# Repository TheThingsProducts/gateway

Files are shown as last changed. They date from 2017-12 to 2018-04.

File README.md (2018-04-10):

# The Things Gateway

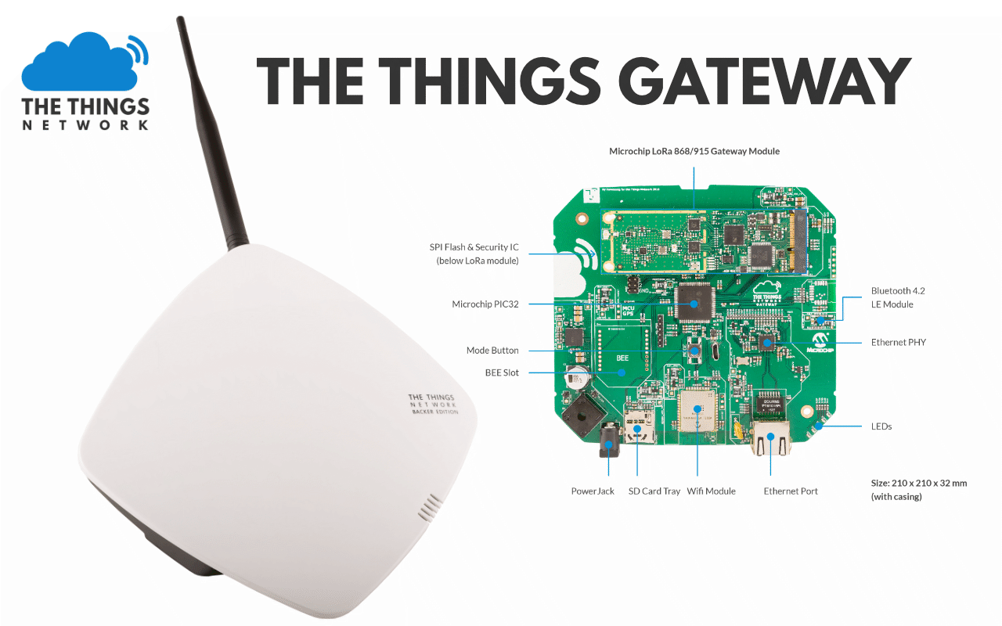
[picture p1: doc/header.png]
The Things Gateway


## Where to buy

A list of resellers can be found [here](https://www.thethingsnetwork.org/the-things-products).

## Enclosure

Designs of the enclosure can be found in the [enclosure](./enclosure) directory. These designs are licensed under a [Creative Commons Attribution-ShareAlike 4.0 International License](http://creativecommons.org/licenses/by-sa/4.0/).

## Hardware

Designs of the hardware can be found in the [hardware](./hardware) directory. These designs are licensed under a [Creative Commons Attribution-ShareAlike 4.0 International License](http://creativecommons.org/licenses/by-sa/4.0/).

## Firmware

Firmware source code is located in the [firmware](./firmware) directory. Firmware source code is released under a [MIT License](https://opensource.org/licenses/MIT).

## Feature Requests, Bug Reports and Support

- For feature requests and bug reports, create an [issue on Github](https://github.com/TheThingsProducts/gateway/issues)
- Community support on our [forum](https://www.thethingsnetwork.org/forum/c/gateways/the-things-gateway)
- Commercial support by [e-mail](mailto:support@thethingsproducts.com)

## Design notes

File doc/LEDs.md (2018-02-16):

# Gateway LEDs

| **LED 1** | **LED 2**  | **LED 3**  | **LED 4**  | **Status** |
| --- | --- | --- | --- | --- |
| On | Slow blink | | | Connecting to the internet |
| On | Fast blink | | | Could not connect to the internet |
| On | On | Slow blink | | Activating |
| On | On | Fast blink | | Could not activate (restart activation from step 1) |
| On | On | On | | Activated |
| On | On | On | On | Connected to the server |

## Details

| **LED** | **State** | **Reason** | **Cause** | **User Action** |
| --- | --- | --- | --- | --- |
| **1 - Power** | Off | No software is running | No power | Make sure the device is powered |
| | | | Incorrect firmware loaded | Make sure the correct firmware is loaded |
| | Slow | Software update in progress | | Wait |
| | On | Software is loaded and running |
| **2 - Internet** | Slow | Checking for internet |
| | Fast | No Ethernet or WiFi connection | No Ethernet link and WiFi connection failed; only possible way to connect is via the gateway’s WiFi access point (AP) | Connect to gateway's AP |
| | On | Has internet |
| **3 - Configuration** | Slow | Activating |
| | Fast | Bad configuration | No ID |Need to configure a gateway ID on the device |
| | | | Already activated | Need to configure valid key on the device |
| | | | Invalid key | Need to configure valid key on the device |
| | | | No router | Need to configure router in the TTN console |
| | | | Invalid URL | Correct URL in the TTN console |
| | On  | Activation successful |
| **4 - Connection** | Slow | Connecting MQTT |
| | On | Connected MQTT |
| **5 - Activity** | Single | Uplink/Downlink |

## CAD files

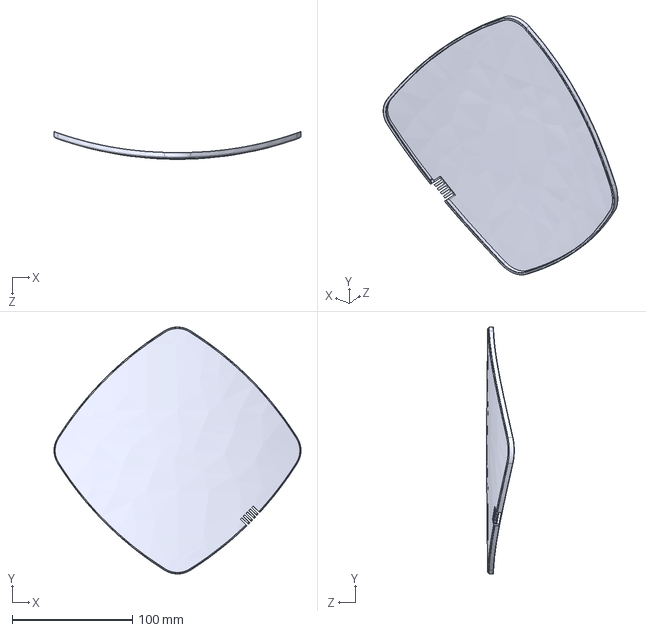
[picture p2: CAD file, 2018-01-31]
enclosure/TheThingsGateway-top.STEP
205.1 x 205.1 x 23.0 mm

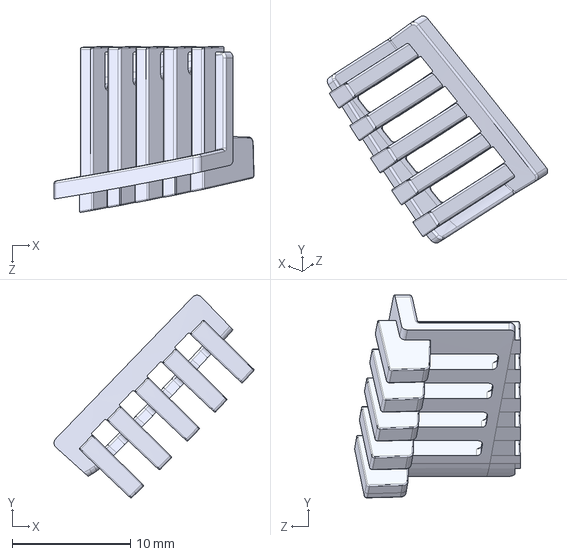
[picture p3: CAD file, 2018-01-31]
enclosure/TheThingsGateway-lightguide.STEP
16.9 x 17.1 x 14.0 mm

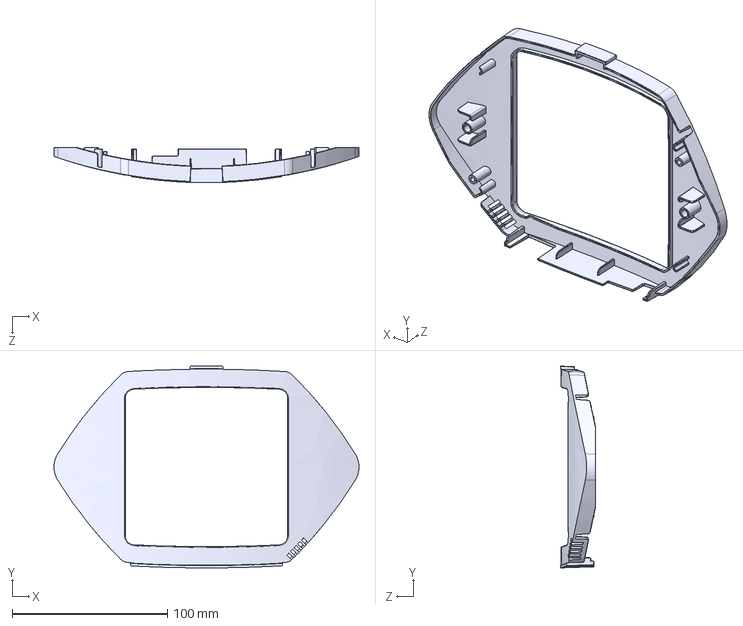
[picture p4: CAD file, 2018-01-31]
enclosure/TheThingsGateway-middle.STEP
196.4 x 130.0 x 22.9 mm

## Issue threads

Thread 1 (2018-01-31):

Reboot Loop - Reboot reason: 0x10 or 0x13

htdvisser, 2018-01-31:
From what I can see in the source code, that's a `RESET_REASON_WDT_TIMEOUT` (`0x10`).

Based on what I see on the [forum](https://www.thethingsnetwork.org/forum/t/ttn-gateway-central/10976) this happens **a lot**.

mbarnig, 2018-02-06:
In the TTN Gateway Central forum there are at least 57 identified users with a looping Gateway.

https://www.thethingsnetwork.org/forum/t/ttn-gateway-central/10976/408?u=mbarnig

johanstokking, 2018-02-06:
Please provide details here, not on the forum. From here we can link to the source files, pull requests and people can watch this issue getting closed.

Pinkfoxi, 2018-02-06:
The same as all other with troubles...
________________________________
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

frbayart, 2018-02-06:
The question is, which kind of details can help ?

grahamehorner, 2018-02-06:
here’s my little video looks almost identical with LEDS and quick flash on module that a reboot loop 🤪 https://twitter.com/grahamehorner/status/957325865892958208

johanstokking, 2018-02-06:
@frbayart @Pinkfoxi @grahamehorner

What could be of help for the maintainers is:

- How often does this occur
- Do you have logs from the gateway, and if so, can you provide them
- Can you tell more about the context, i.e. which model (915, 868), ethernet or wifi connected, etc

frbayart, 2018-02-06:
- this occur since I have connected my gateway there are 3 days
- I have tested on WiFi and ethernet ; I have also tested on a second internet connection
- model TTN Gateway Backer Edition 868

At this time I have no logs from the gateway , I guess I need to connect a serial on it to get logs right ?

grahamehorner, 2018-02-06:
- reboot interval approx. 30 seconds
- both WiFi and Ethernet inside/outside of firewall and different business ISPs
- TTN Gateway Backer Edititon - European 868

OK, looks like my gateway is officially STUFFED!!! NOW!! after a few days powered off, I power on today and only the first (Power) LED is solid with the second LED flashing rapidly, and its been like this for hours!?

robdobsn, 2018-02-06:
```
LORA: version: 01
LORA: Configuration failed, retry
LORA: Starting reconfiguration
LORA: version: 01
LORA: Configuration failed, retry
LORA: RESET MODULE
LORA: ChaSNTP: State change from 0 to 0
SNTP: State change from 0 to 0

**************************
*   The Things Network   *
*      G A T E W A Y     *
**************************
Firmware name: AmazingAckermann, type: 0, version: 1.0.0, commit: 917719b9, timestamp: 1498499973
Bootloader revision: 1, commit: 7167873a, timestamp: 1496411298
Build time: Jun 26 2017 19:59:53
Reboot reason: 0x13
BOOT: (persisted info) 6F 72 72 65 01 03 0A 3F 15 84 13 0F B1 25 98 B0

WIFI: Entering state 0
WIFI: Entering SCAN state 0

MAIN: Initialisation complete
LORA: Changing state from 0 to 0

MAIN: Leaving state 0
MAIN: Entering state 1
FLASH: Magic bytes found: wifi config present
FLASH: Magic bytes found: activation data present
FLASH: Magic bytes not found: no stored FOTA data present
FLASH: Loading Firmware Data
CNFG: (Firmware HASH (sha256)) FF FF FF FF FF FF FF FF FF FF FF FF FF FF FF FF FF FF FF FF FF FF FF FF FF FF FF FF FF FF FF FF
FLASH: Loading WiFi Data
CNFG: WiFi SSID:      rdint01
CNFG: WiFi key:       golgofrinsham
CNFG: WiFi conn_type: 1
CNFG: WiFi sec_type:  4
FLASH: Loading Activation Data
CNFG: Gateway ID:         atomic14-1
CNFG: Gateway Key:        ttn-account-v2.B8leUhot-xnHx1Vbrc8s1ZNcBzYuABED6BB71BXcv7hbDV2HxTGOh19yGIOwpdxLZrw70irKTZ4T5TcvH9BjIQ
CNFG: Account Server URL: https://account.thethingsnetwork.org
CNFG: Locked:             true
CNFG: Locked first time:  false

MAIN: Leaving state 1
MAIN: Entering state 2
INET: State change to 0
LORA: Initialisation complete
LORA: Changing state from 0 to 1
WIFI: Entering state 1
ETH: IP Address: 0.0.0.0
WIFI: Entering state 4
WIFI: Entering SCAN state 1
Scan is completed successfully
WIFI: Entering SCAN state 2
WIFI: Entering SCAN state 5
WIFI: Entering SCAN state 0
WIFI: Entering state 2
WIFI: Disabling modules
Head magic match void: trying to free an already freed block, ignore
WIFI: Entering state 3
SNTP: State change from 0 to 1
WIFI: Enabling modules for client
WIFI: Entering state 6

>WIFI: IP Address: 0.0.0.0
CB: INET: Gateway has WiFi
INET: State change to 2
INET: Connected to a network, waiting for DHCP lease, checking validity with ping
SNTP: State change from 1 to 2
LORA: Wait init complete, waiting for application.
LORA: Changing state from 1 to 2
WIFI: IP Address: 192.168.86.68
INET: State change to 3
INET: Ping probe
INET: Error sending probe on Eth
INET: Ping response from MRF24WN, set as default
INET: State change to 4
SNTP: State change from 2 to 3
MON: SYS Stack size: 3967
MON: heap usage: 147KB (156KB), free: 192KB
SNTP: State change from 3 to 4
SNTP: State change from 4 to 5
SNTP: State change from 5 to 6
SNTP: State change from 6 to 7
INET: State change to 5

MAIN: Leaving state 2
MAIN: Entering state 3

CNFG: Load online user config state change to 4
HTTP: Close active socket 0
CONF: ERROR REQUEST

CNFG: Downloading gateway configuration failed

CNFG: Load online user config state change to 8

CNFG: Communication ERROR

MAIN: Leaving state 3
MAIN: Entering state 2
INET: State change to 0
WIFI: Disabling modules
SNTP: State change from 7 to 8
CB: Disconnect
Head magic match void: trying to free an already freed block, ignore
SNTP: State change from 8 to 1
WIFI: Entering state 3
WIFI: Enabling modules for client
WIFI: Entering state 6
WIFI: IP Address: 0.0.0.0
CB: INET: Gateway has WiFi
INET: State change to 2
INET: Connected to a network, waiting for DHCP lease, checking validity with ping
SNTP: State change from 1 to 2
SNTP: State change from 2 to 3
SNTP: State change from 3 to 4
SNTP: State change from 4 to 5
MON: SYS Stack size: 3961
MON: heap usage: 147KB (157KB), free: 192KB
INET: State change to 3
INET: Ping probe
INET: Error sending probe on Eth
CB: INET: Ping Timeout
INET: Ping probe
INET: Error sending probe on Eth
SNTP: State change from 5 to 6
INET: Ping Timeout
INET: Ping probe
INET: Error sending probe on Eth
MON: SYS Stack size: 3961
MON: heap usage: 148KB (157KB), free: 191KB
INET: Ping Timeout
INET: State change to 1
WIFI: Disabling modules
SNTP: State change from 6 to 8
CB: Disconnect
Head magic match void: trying to free an already freed block, ignore
SNTP: State change from 8 to 1
WIFI: Entering state 3
WIFI: Entering state 4
WIFI: Entering SCAN state 1
Scan is completed successfully
WIFI: Entering SCAN state 2
WIFI: Entering SCAN state 3
Head magic match void: trying to free an already freed block, ignore
SNTP: State change from 1 to 1
WIFI: Entering SCAN state 4
WIFI: Entering SCAN state 5
WIFI: Entering SCAN state 0
WIFI: Entering state 5
WIFI: Enabling modules for server
WIFI: Entering state 6
WIFI: IP Address: 192.168.84.1
CB: MON: SYS Stack size: 3961
MON: heap usage: 147KB (157KB), free: 192KB
MON: SYS Stack size: 3961
MON: heap usage: 147KB (157KB), free: 192KB
MON: SYS Stack size: 3961
MON: heap usage: 147KB (157KB), free: 192KB
MON: SYS Stack size: 3961
MON: heap usage: 147KB (157KB), free: 192KB
MON: SYS Stack size: 3961
MON: heap usage: 147KB (157KB), free: 192KB
MON: SYS Stack size: 3961
MON: heap usage: 147KB (157KB), free: 192KB
MON: SYS Stack size: 3961
MON: heap usage: 147KB (157KB), free: 192KB
MON: SYS Stack size: 3961
MON: heap usage: 147KB (157KB), free: 192KB
MON: SYS Stack size: 3961
MON: heap usage: 147KB (157KB), free: 192KB
MON: SYS Stack size: 3961
MON: heap usage: 147KB (157KB), free: 192KB
MON: SYS Stack size: 3961
MON: heap usage: 147KB (157KB), free: 192KB
MON: SYS Stack size: 3961
MON: heap usage: 147KB (157KB), free: 192KB
INET: Trying to connect to WiFi router again (after 120 seconds)
INET: State change to 0
WIFI: Disabling modules
CB: Disconnect
Head magic match void: trying to free an already freed block, ignore
SNTP: State change from 1 to 1
WIFI: Entering state 3
WIFI: Enabling modules for client
WIFI: Entering state 6
WIFI: IP Address: 0.0.0.0
CB: INET: Gateway has WiFi
INET: State change to 2
INET: Connected to a network, waiting for DHCP lease, checking validity with ping
SNTP: State change from 1 to 2
MON: SYS Stack size: 3961
MON: heap usage: 147KB (157KB), free: 192KB
INET: State change to 3
INET: Ping probe
INET: Error sending probe on Eth
SNTP: State change from 2 to 6
INET: Ping Timeout
INET: Ping probe
INET: Error sending probe on Eth
WIFI: IP Address: 192.168.86.68
INET: Ping Timeout
INET: Ping probe
INET: Error sending probe on Eth
INET: Ping response from MRF24WN, set as default
INET: State change to 5

MAIN: Leaving state 2
MAIN: Entering state 3

CNFG: Load online user config state change to 4
HTTP: Starting connection
HTTPS: Connection Opened: Starting TLS Negotiation
HTTP: Wait for TLS Connect
HTTP: TLS Connection Opened: Starting Clear Text Communication
HTTP: Got 1289 bytes
MON: SYS Stack size: 2837
MON: heap usage: 228KB (233KB), free: 111KB
HTTP: Connection Closed
HTTP: Close active socket 1
CONF: Parsing response token: HTTP/1.1 200 OK
CONF: ROUTER URL: mqtts://bridge.eu.thethings.network:8883
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
grahamehorner, 2018-02-06:
interesting note in code

```
static void restart_lora_configuration(void)
{
    SYS_DEBUG(SYS_ERROR_FATAL, "LORA: RESET MODULE\r\n");
    DRV_USART_Close(appData.USARTHandle);
    **// TODO Verify untested fix. Here we power cycle the module as resetting (done in loraInit) the module was not
    // enough.**
    loraSet(false);
    vTaskDelay(100 / portTICK_PERIOD_MS);
    loraSet(true);
    _setState(APP_LORA_INIT);
}
```

grahamehorner, 2018-02-06:
BOOT: (persisted info)
[6F 72 72 65]  = magic -  errA ? should be erro according to code ?
[01]                 = type   -   ERROR_MESSAGES_TYPE_POWER_CYCLE

and based on the information at hand given the magic number is incorrect according to the code I've seen; this would suggest a memory pointer issue that is corrupting something ?

cyberjunky, 2018-02-07:
@johanstokking

**Here my complete logs with extra debugging enabled (own compiled fw)**

I compile my own fw from this github repo, I enabled extra debugging (although it's just some lora and flash debugging)

By doing this:
`vi src/system_config/TTN_Gateway_v1/system_init.c

SYS_DEBUG_INIT debugInit =
{
    .moduleInit = {0},
    .errorLevel = SYS_ERROR_DEBUG
};
`
I first deleted activation from gw, and flashed fw via sd card, I then started activation page, and created new gateway. Connected laptop via wifi and choose Ethernet as network, then gw restarted and I lost internet connection on my laptop, see it get activated and connected in ttn console, it send some packets and stayed running for 223 second, then it rebooted all of a sudden, and started again, but seems to fail te get response from NTP servers, it tries for a while and seem to get internet connection again, when it gets TLS traffic, shortly after that you see this in the log:

> MON: heap usage: 263KB (269KB), free: 76KB
   SNTP: State change from 0 to 0
   SNTP: State change from 0 to 0

Then it reboots with all 5 leds on, off, on, off on, etc etc... No logging in console. The gw doesn't get out of this loop. I can reproduce this many times since I got the gateway.

As you can see I don't have the LORA RESET messages like others have in the logs.

See info screen shots and logs attached, fresh activation....txt and 1.png are before sudden reboot, it continues in sudden reboot....txt and 2.png but at that end it starts boot looping.

Also see the last line in sudden reboot...txt, I see this every time when a reboot loop starts:

> HTTP: Close active socket 1300,"radio":1,"bandw

So right after closing the TLS connection, some output of LORA module garbled:

>
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

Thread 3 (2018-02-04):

Is it on purpose LoRa_Tx = LoRa_Rx on gateway/hardware/TTN_Gateway_V2.3.1.pdf

mchevroulet, 2018-02-04:
Is it on purpose that LoRa_TX is shorted with LoRa_Rx on schematics lora.SchDoc in gateway/hardware/TTN_Gateway_V2.3.1.pdf ? Or is it just a print artefact ?

This is page 8/9, revision 1.0 of document dated 2018-1-31.

Closed 2018-03-15.

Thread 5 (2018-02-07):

Gateway Boot Issues

grahamehorner, 2018-02-07:
My gateway was effected by the reboot issue; now the gateway fails to boot, the power LED is solid; while the second LED is flashing rapidly ?

grahamehorner, 2018-02-07:
I have attempt to update via SD card without success, there is no output via serial port logs

johanstokking, 2018-02-07:
Duplicate of #1

grahamehorner, 2018-02-07:
This is not a duplicate of #1 as I cant connect to the gateway at all the AP is not visible and the gateway is not rebooting but is stuck with regards the boot sequence with power LED solid and 2nd LED flashing rapidly; which is quite a different set of issues to the Reboot Loop

grahamehorner, 2018-02-07:
Please reopen

grahamehorner, 2018-02-07:
I'm unsure this is a soft/firmware issue, as after many attempts and reboots the gateway is now showing up as an AP and I'm able to connect; and the gateway now looks to have successfully updated it's firmware

Version Info |  -- | -- Hardware: | v1
Bootloader: | r1-7167873a (2017-06-02T13:48:18Z)
Firmware: | v1.0.1-0407f7eb (2018-02-06T10:58:41Z)

however the #1 is still present; If hardware issues are still to be logged; this IMHO is definitely an odd one? may be a dry joint or something? physical with the gateway

grahamehorner, 2018-02-16:
The gateway is now back to not showing up as an AP or updating, this time  tried 14 reboots, nothing still not seeing the gateway as an AP so can’t verify if the status?  LEDs are same as above

grahamehorner, 2018-02-20:
After leaving the gateway off for approx. 3days my gateways is still in an unstable state where I'm unable to see the gateways as an access point or update the firmware via the SD card after a full reset ?

grahamehorner, 2018-02-24:
other update booted the gateway this morning, and this time it shows up as an AP; will try and update firmware

grahamehorner, 2018-02-25:
Update seemed to work, then gateway was stuck in reboot loop 😭

grahamehorner, 2018-02-28:
my gateway is shown that the card is ND this never changes even after rebooting or full reset, when the gateway decides to start? Please can any one advise?!

KrishnaIyer, 2018-09-27:
@grahamehorner: Please let us know if you still face this issue after  upgrading to firmware `v1.0.5` or if we can close this.

grahamehorner, 2018-09-27:
@KrishnaIyer I'm unable to perform any update to the gateway as detailed in numerous posts on forums, the gateway is unresponsive to any attempt to update or connection via FDTI, its now an as much use as an expensive door stop or chocolate fireguard :'(  very very frustrating especially when it has been so long without a resolution or an offer of exchange/replacement unit

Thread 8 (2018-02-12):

Gateway loses network connection and needs power cycle to recover

avbentem, 2018-02-12:
My gateway lost its WiFi connection over an hour ago, and could not recover without cycling its power, like others have reported on the forum as well. Some observations:

## While failing to reconnect

- I think it had been running for about 20 hours. (Certainly not a full day; I took a picture at 9 PM last night, when it was not connected; at around 6 PM today it showed as "Last seen: 54 minutes ago".)

- It might have been in AP mode (LED 2 flashing slow and fast).

- Plugging in a debug cable restarted the gateway.

- The unexpected reset of the gateway did not resolve this.

- After the reset, it kept reporting things like:

    ```text
    INET: Trying to connect to WiFi router again (after 120 seconds)
    INET: State change to 0
    MON: SYS Stack size: 3959
    MON: heap usage: 148KB (148KB), free: 191KB
    INET: No Ethernet and WiFi link (after 10 seconds)
    INET: State change to 1
    ```

- The FRITZ!Box 7360 WiFi AP did not log any connection attempts.

- Restarting the WiFi AP did not resolve this. All other devices (Sonos, Apple TV, Chromecast, laptop, tablet, telephone) reconnected just fine.

- Attaching an ethernet cable did not resolve this. The connector's LEDs were flashing, but I forgot to check if the router showed a connection.

- Finally cycling power resolved it.

## During normal operation

- When connected to ethernet and unplugging the cable, it nicely recovers by connecting to WiFi. (LED 2 flashing for some time, while LED 1 and 3 are solid.)

- Restarting the AP when the gateway is connected to its WiFi, makes the gateway reboot:

    ```text
    LORA: Accepted packet
    MQTT: Sending UPLINK failed: -1

    MAIN: MQTT error

    MAIN: Leaving state 5
    SNTP: State change from 0 to 0
    SNTP: State change from 0 to 0
    ```

    Next, when it cannot connect to WiFi after restarting, it starts in AP mode (LED 2 flashing) but eventually connects to WiFi again, and all is good.

avbentem, 2018-02-14:
It kept running for 36 hours, but eventually got into a non-recoverable network problem again. The new logs shows:

- It _can_ recover from some MQTT problems (10:07 this morning, Amsterdam time).

- Sometimes it cannot recover from MQTT problems, even though it has an internet connection and can nicely fetch its configuration from the internet.

So I wonder:

- Could the non-recoverable problem have started by MQTT problems on the server, around 2018-02-14 17:05:15 (Amsterdam time), and be different MQTT problems than the one it could recover from?

## Nicely recovering from `MQTT: Sending status failed` (after running for 36 hours)

- Running my own firmware, with debug logging enabled. (See PR #7.)

- Logging started 2018-02-12 22:42:10. I'm not sure how long the gateway was running then, but not for very long.

- It failed about 36 hours later, `MQTT: Sending status failed`, but recovered. All logs here have `MON:`-lines removed for brevity:

	```text
	[2018-02-14 10:06:11] MQTT: Sending UPLINK OK
	[2018-02-14 10:06:22] MQTT: Sending status packet
	[2018-02-14 10:06:22] MQTT: Sending status succeeded: 1351
	[2018-02-14 10:06:47] LORA: Packet dropped! Bad CRC
	[2018-02-14 10:06:52] MQTT: Sending status packet
	[2018-02-14 10:06:52] MQTT: Sending status succeeded: 1352
	[2018-02-14 10:07:07] LORA: Packet dropped! Bad CRC
	[2018-02-14 10:07:22] MQTT: Sending status packet
	[2018-02-14 10:07:22] MQTT: Sending status succeeded: 1353
	[2018-02-14 10:07:52] CB: MQTT: Sending status packet
	[2018-02-14 10:07:54] MQTT: Sending status failed
	[2018-02-14 10:07:54]
	[2018-02-14 10:07:54] MAIN: MQTT error
	[2018-02-14 10:07:55]
	[2018-02-14 10:07:55] MAIN: Leaving state 5
	[2018-02-14 10:07:57] MAIN: Entering state 6
	[2018-02-14 10:07:57] INET: State change to 0
	[2018-02-14 10:07:57] WIFI: Disabling modules
	[2018-02-14 10:07:57] SNTP: State change from 7 to 8
	[2018-02-14 10:07:57] CB: Disconnect
	[2018-02-14 10:07:57] Head magic match void: trying to free an already freed block, ignore
	[2018-02-14 10:07:57] SNTP: State change from 8 to 1
	[2018-02-14 10:07:57] WIFI: Entering state 3
	[2018-02-14 10:07:58] WIFI: Enabling modules for client
	[2018-02-14 10:07:58] WIFI: Entering state 6
	[2018-02-14 10:07:58] WIFI: IP Address: 0.0.0.0
	[2018-02-14 10:08:00] CB: INET: Gateway has WiFi
	[2018-02-14 10:08:00] INET: State change to 2
	[2018-02-14 10:08:00] INET: Connected to a network, waiting for DHCP lease, checking validity with ping
	[2018-02-14 10:08:01] SNTP: State change from 1 to 2
	[2018-02-14 10:08:04] CB: MON: SYS Stack size: 2833
	[2018-02-14 10:08:05] INET: State change to 3
	[2018-02-14 10:08:05] INET: Ping probe
	[2018-02-14 10:08:05] INET: Error sending probe on Eth
	[2018-02-14 10:08:05] LORA: Accepted packet
	[2018-02-14 10:08:06] SNTP: State change from 2 to 6
	[2018-02-14 10:08:09] INET: Ping Timeout
	[2018-02-14 10:08:09] INET: Ping probe
	[2018-02-14 10:08:09] INET: Error sending probe on Eth
	[2018-02-14 10:08:11] LORA: Accepted packet
	[2018-02-14 10:08:13] INET: Ping Timeout
	[2018-02-14 10:08:13] INET: Ping probe
	[2018-02-14 10:08:13] INET: Error sending probe on Eth
	[2018-02-14 10:08:16] CB: Disconnect
	[2018-02-14 10:08:17] INET: Ping Timeout
	[2018-02-14 10:08:17] INET: State change to 1
	[2018-02-14 10:08:17] WIFI: Disabling modules
	[2018-02-14 10:08:17] Head magic match void: trying to free an already freed block, ignore
	[2018-02-14 10:08:17] SNTP: State change from 6 to 1
	[2018-02-14 10:08:17] WIFI: Entering state 3
	[2018-02-14 10:08:18] WIFI: Entering state 4
	[2018-02-14 10:08:18] WIFI: Entering SCAN state 1
	[2018-02-14 10:08:18] Scan is completed successfully
	[2018-02-14 10:08:18] WIFI: Entering SCAN state 2
	[2018-02-14 10:08:18] WIFI: Entering SCAN state 3
	[2018-02-14 10:08:18] Head magic match void: trying to free an already freed block, ignore
	[2018-02-14 10:08:18] SNTP: State change from 1 to 1
	[2018-02-14 10:08:18] WIFI: Entering SCAN state 4
	[2018-02-14 10:08:19] WIFI: Entering SCAN state 5
	[2018-02-14 10:08:19] WIFI: Entering SCAN state 0
	[2018-02-14 10:08:19] WIFI: Entering state 5
	[2018-02-14 10:08:19] WIFI: Enabling modules for server
	[2018-02-14 10:08:19] WIFI: Entering state 6
	[2018-02-14 10:08:19] WIFI: IP Address: 192.168.84.1
	[2018-02-14 10:08:20] LORA: Accepted packet
	[2018-02-14 10:08:24] CB: MON: SYS Stack size: 2833
	[2018-02-14 10:08:36] LORA: Accepted packet
	[2018-02-14 10:08:43] LORA: Accepted packet
	[2018-02-14 10:08:43] LORA: Packet dropped! Bad CRC
	[2018-02-14 10:09:12] LORA: Accepted packet
	[2018-02-14 10:09:17] LORA: Accepted packet
	[2018-02-14 10:09:23] LORA: Accepted packet
	[2018-02-14 10:09:23] LORA: Packet dropped! Bad CRC
	[2018-02-14 10:10:17] INET: Trying to connect to WiFi router again (after 120 seconds)
	[2018-02-14 10:10:17] INET: State change to 0
	[2018-02-14 10:10:17] WIFI: Disabling modules
	[2018-02-14 10:10:17] CB: Disconnect
	[2018-02-14 10:10:17] Head magic match void: trying to free an already freed block, ignore
	[2018-02-14 10:10:17] SNTP: State change from 1 to 1
	[2018-02-14 10:10:17] WIFI: Entering state 3
	[2018-02-14 10:10:18] WIFI: Enabling modules for client
	[2018-02-14 10:10:18] WIFI: Entering state 6
	[2018-02-14 10:10:18] WIFI: IP Address: 0.0.0.0
	[2018-02-14 10:10:19] CB: INET: Gateway has WiFi
	[2018-02-14 10:10:19] INET: State change to 2
	[2018-02-14 10:10:19] INET: Connected to a network, waiting for DHCP lease, checking validity with ping
	[2018-02-14 10:10:20] SNTP: State change from 1 to 2
	[2018-02-14 10:10:21] WIFI: IP Address: 192.168.178.53
	[2018-02-14 10:10:23] LORA: Kick LoRa module with ACK after not acked it for 60s
	[2018-02-14 10:10:24] INET: State change to 3
	[2018-02-14 10:10:24] INET: Ping probe
	[2018-02-14 10:10:24] INET: Error sending probe on Eth
	[2018-02-14 10:10:24] INET: Ping response from MRF24WN, set as default
	[2018-02-14 10:10:24] INET: State change to 5
	[2018-02-14 10:10:24]
	[2018-02-14 10:10:24] MAIN: Leaving state 6
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
avbentem, 2018-02-18:
Update: it has been running for over 3 days (since 2018-02-14 23:18) now. It has seen a bunch of `MQTT: Sending UPLINK failed` and `MQTT: Sending status failed`, has rebooted 8 times (3 of which for `MAIN: Rebooting gateway for firmware update check`), but has always recovered during the last 3 days.

(Still running my own patched firmware, [being `develop` from February 14th with debug logging enabled](https://github.com/TheThingsProducts/gateway/issues/1#issuecomment-365746884).)

grahamehorner, 2018-02-18:
@avbentem that’s great news, so given the gateway reboots every 24hrs in the code, you’ve got 5 unattend reboots which is a MASSIVE improvement by far, great work

avbentem, 2018-02-18:
To clarify, @grahamehorner, the 5 unwanted reboots occurred after running into a `MAIN: MQTT error` (which, however, does not _always_ imply a reboot; often it just recovers without such reboot and I've not yet discovered in which cases it deems a reboot required), and seem unrelated to reboot issues during activation, like those reported in #1.

I'm eager to test what happens when I make my router disconnect the WiFi, or shutdown the router altogether. But I don't want to interfere with the current test which meanwhile has given me a log file of almost 4 days now, and which may be useful to compare to server side logs, to find the cause of MQTT issues.

grahamehorner, 2018-02-18:
@avbentem that sound like a great plan, wondering if the gateway should have some SNMP added late to allow remote diagnostics and or management;  but it great to hear that progress is begin made

johanstokking, 2018-02-20:
@avbentem do you have the dates and times of this disconnect? We have had some issues with EU endpoints, including MQTT, very recently. This may be server initiated disconnects which the gateway recovered from naturally.

cc @htdvisser

avbentem, 2018-02-20:
Still running, almost 6 days now. And it nicely recovered at about 17:40 GMT+1, without me interfering, from the major EU region problems that [were happening today](https://www.thethingsnetwork.org/forum/t/eu-region-routing-services-major-outage/12768).

During the problems I got into regular reboots with `RQMQTT: Connection failed` followed by `MAIN: MQTT error` and `Reboot reason: 0x10`.

At other times in the recent logs I see `MQTT: Connection lost` (rather than `failed`) like the following:

```text
LORA: Accepted packet
MQTT: Sending UPLINK OK
LORA: Accepted packet
MQTT: Sending UPLINK OK
MQTT: Sending status packet
MQTT: Sending status succeeded: 1
MQTT: Connection lost

MAIN: MQTT error
```

...followed by many:

```text
MQTT: GOT IP: 52.169.76.203
Connecting to: 52.169.76.203
MQTT: Opening socket timed out, restarting
MQTT: GOT IP: 52.169.76.203
Connecting to: 52.169.76.203
MQTT: Opening socket timed out, restarting
MQTT: GOT IP: 52.169.76.203
Connecting to: 52.169.76.203
MQTT: Opening socket timed out, restarting
```

So, it seems `Connection failed` (often) yields a reboot, but `Connection lost` makes the firmware try forever.

avbentem, 2018-02-20:
@johanstokking, here's a full log since February 14th:

[arjan-gateway-20180220.log.zip](https://github.com/TheThingsProducts/gateway/files/1741101/arjan-gateway-20180220.log.zip)

Like earlier, this is using my own firmware, based on the February 14th `develop` branch, only changed to enable debug logging and the debug cable's baud rate. It's been compiled with a free version (or a trial?) of the Microchip XC32 v1.42 compiler.

avbentem, 2018-02-20:
@johanstokking and @htdvisser I've edited my comment above a few times.

avbentem, 2018-03-02:
Quick update: my gateway nicely recovered from today's https://status.thethings.network/incident/45 So, it has not needed any reboot since February 14th.

```text
[2018-03-02 10:28:05] MQTT: Sending UPLINK OK
```

However, half an hour later, it ran into:

```text
[2018-03-02 11:02:43] MQTT: Sending UPLINK OK
[2018-03-02 11:02:45]
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

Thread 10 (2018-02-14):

Unable to turn off wifi AP mode on the gateway

sourceperl, 2018-02-14:
Hi,

I use the ethernet link to connect the gateway to the internet.

After activation the wifi AP mode is not turn off and my gateway always broadcast the SSID ""Things-Gateway-0001ECxxxxxx". The default password "thethings" also remain active... It's really not secure.

I'm unable to fix  this. I try the embedded web manager, the serial debug (the wifi cmd seem not work) and https://console.thethingsnetwork.org/gateways.

My firmware is :
(Firmware HASH (sha256)) 69 AE B7 78 1F 49 4E 7F BC B6 C7 CD 9C 59 4F 5D FA AA 3D 81 D4 9C 56 90 A6 83 81 98 FF 18 88 6A

Bootloader is:
Firmware name: AmazingAckermann, type: 0, version: 1.0.0, commit: 917719b9, timestamp: 1498499973
Bootloader revision: 1, commit: 7167873a, timestamp: 1496411298
Build time: Jun 26 2017 19:59:53

sourceperl, 2018-02-15:
after some test, i find the command "if wlan0 down" this turn off wifi access point but it's not persistent after reboot.

IJeffray, 2018-02-20:
I would very much like to run with Ethernet only and the WLAN module completely disabled.  For security, and for keeping the air clear.   I'm very surprised this isn't an option already as it would surely be simple to implement.   It could even be 'automatic' - if Ethernet is present at bootup, disable the Wifi -- no need for any user interface.

cyberjunky, 2018-02-24:
Sometimes you might need the wifi to be able to reconfigure/activate it, maybe it's an idea to toggle wifi on off by using a file flag on the sd card, so when a user creates a file on the sd card named `'nowifi' `disable it.

wintermi, 2018-03-15:
Just got my TTN Gateway and have the same issue.  I only want to use the Ethernet connection and the only way I have found at the moment to remove the Wifi AP is to actually connect the Wifi.  Not a good solution as now both Wifi & Ethernet is configured.

lanmarc77, 2019-02-18:
I am not sure if I understood this thread. But I still see the SSID being broadcasted in the current firmware even though I have working ethernet connection and /info also only displays Ethernet as connection type.
Inserting the following code in app_wifi.c at line 354 finally stops the broadcast and also saves 0.3W of power:

`_activeConfig = CNFG_NONE;`
`_event=EVENT_NONE;`
`return;`

Who also wants to disable the built in http server comments line 739 in system_config.h:

`//#define TCPIP_STACK_USE_HTTP_SERVER`

hagenbuch, 2019-02-28:
Does this mean I have to compile and install the complete firmware for the TTN gateway?

If yes, I'd rather wait until the first scandal shows up where some attacker exploited a company successfully and came in through their open Things Gateway AP /s

lanmarc77, 2019-02-28:
Yes it does mean compiling and installing the firmware yourself. If you do have the .hex file you only would need an SD card to actually update the gateway. Also compiling is not really more than installing the freely availble IDEs linked in the readme of this repository and cloning this repository. As I already did the detective work how to minimally change the code to achieve the given features this can be done in under an hour easily.
And also yes you are free to wait until something (might) happen but then I do not see how this helps in any way to add features WE want. I so value the possibility to have an open device, knowing I do not get an SLA but be able to do something with it myself.

KrishnaIyer, 2019-03-06:
@lanmarc77: what is the version of your firmware?

lanmarc77, 2019-03-06:
@KrishnaIyer The base of the mentioned modification was v1.0.5 which is the current version of the firmware since July 2018

MartinNPN, 2019-05-14:
@lanmarc77 thanks for the easy solution :)

devZer0, 2023-05-16:
this ticket is closed - but how can i disable wifi now ?

what do i need to do ?

Closed 2018-04-21.

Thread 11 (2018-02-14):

Bootloader code or image availability?

cyberjunky, 2018-02-14:
My gateway stopped working all together it seems, no lights lit up other than the power circuit ones (2) , no working firmware updates via SD card or responses on mode button presses can be seen.
Will the bootloader code and/or image (hex file) be made available? Either public in this repo or privately disclosed/shared so I can try to get it running again by re-flashing it via ISCP port using a debugger tool like PicKit3 or ICD3.

cyberjunky, 2018-02-20:
@rish-c Rich-c are you able to supply me the bootloader or memory hex to be flashed using a debugger tool so my gw boots again? Maybe even via PM.
This way I can perhaps get it up and running again and start helping to debug the timing issues together with @avbentem

cyberjunky, 2018-02-23:
Yes, I managed to unbrick my gateway (which was bricked due to my own fault) I flashed the bootloader.hex from the feature/merging_bootloader branch using my ICD3  and it came to life again with bootloader r2, it didn't reboot with reason 0x10 ever since!
I also flashed the firmware from the same branch and for the first time ever I got my devices to use the gateway, it has traffic! Some prove...
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

cyberjunky, 2018-02-24:
I forgot to ask; what is the use case of the firmware-with-bootloader.hex file? Flashing it using the ICD3 didn't result in a working gateway, only after I flashed the bootloader.hex it started to run. The next morning it still runs without a glitch, before this the longest run period was 3-4 minutes.

martinichka, 2018-02-24:
Hi Rob,

The firmware-with-bootloader.hex is a combination of the bootloader with
the latest application. Such a file is used during production, and should
only be programmed using an external programmer (so no via SD card).

So the fact that it did not work when you flashed the with-bootloader image
using ICD is blocking this PR.

We will look in to it.

The fact that it did reboot after since is due to the corrected clock
settings. For now only possible to change by an external programmer. As you
know we are working on a solution that does not require an external
programmer.

Marten

Op za 24 feb. 2018 08:27 schreef Ron Klinkien <notifications@github.com>:

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

cyberjunky, 2018-02-24:
Marten, I noticed the clock setting changes in the commit.
About the firmware-with-bootloader file I flashed it with the default settings like in the screenshot above. But I noticed with this file and with bootloader.hex that the programmer gave a warning about code that is located at addresses that do not exist when loading the hex, this seems bogus for at least one of them as flashing with bootloader.hex file succeeded anyway.
This the message I'm referring too:

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

If you want me to re-test something let me know.

martinichka, 2018-02-24:
If you could re-test with a full erase and flash the firmware-with-bootloader.hex, to see if that is running, that would be a great help. On the devices here it is working and it is the standard procedure at production. The `contains code that is located at addresses that do not exist on the PIC32MZ2048EFM144` we also noticed. It is not new, but I will look in to that.

cyberjunky, 2018-02-24:
What I did to brick it (if i remember correctly) is flashing the firmware.hex to the device using the ICD3, when all the lights went out and stayed out then I realized (a bit late) that the bootloader was missing in the file and gone from my gateway. I didn't test re-flashing after the bootloader.hex succeeded.
I fully erased and re-flashed with firmware-with-bootloader.hex just now 5 times in a row, and it worked flawlessly.
So you can unblock this PR, probably the wrong state without erase first was the cause.

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

martinichka, 2018-02-24:
That is great news. Thanks for retesting.

htdvisser, 2018-03-12:
We added the bootloader in PR #16; Links to hex files with firmware + bootloader are added to the [README in firmware dir](https://github.com/TheThingsProducts/gateway/tree/develop/firmware#firmware-with-bootloader) (currently only in `develop`, expected be merged to `master` soon)

Closed 2018-03-12.

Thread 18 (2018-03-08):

Not connecting to Network / Gateway Card not defined

samuel-puschacher, 2018-03-08:
Hello,
I can't get my Gateway connecting to TTN
I get stuck at Step 4.
When I open the Gateway Info Page I get the following:
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

When I refresh the Page, the LoRa Config is lost, the Concentrator not defined.
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

I tried WiFi & Ethernet in many Combinations and different Networks. Also reset the Gateway, by pressing the Button during Power up.

Edit: It seems to be in a Boot loop
```

**************************
*   The Things Network   *
*      G A T E W A Y     *
**************************
Firmware name: AmazingAckermann, type: 0, version: 1.0.0, commit: 917719b9, timestamp: 1498499973
Bootloader revision: 1, commit: 7167873a, timestamp: 1496411298
Build time: Jun 26 2017 19:59:53
Reboot reason: 0x43
BOOT: (persisted info) 6F 72 72 65 01 03 0E 9A 98 8A F2 4E 49 9A 09 B4

WIFI: Entering state 0
WIFI: Entering SCAN state 0

MAIN: Initialisation complete
LORA: Changing state from 0 to 0

MAIN: Leaving state 0
MAIN: Entering state 1
FLASH: Magic bytes found: wifi config present
FLASH: Magic bytes found: activation data present
FLASH: Magic bytes not found: no stored FOTA data present
FLASH: Loading Firmware Data
CNFG: (Firmware HASH (sha256)) FF FF FF FF FF FF FF FF FF FF FF FF FF FF FF FF FF FF FF FF FF FF FF FF FF FF FF FF FF FF FF FF
FLASH: Loading WiFi Data
CNFG: WiFi SSID:      RP.1.net
CNFG: WiFi key:       ********
CNFG: WiFi conn_type: 1
CNFG: WiFi sec_type:  4
FLASH: Loading Activation Data
CNFG: Gateway ID:         ttn-noe-001
CNFG: Gateway Key:        ttn-account-v2.******************************************************************
CNFG: Account Server URL: https://account.thethingsnetwork.org
CNFG: Locked:             true
CNFG: Locked first time:  false

MAIN: Leaving state 1
MAIN: Entering state 2
INET: State change to 0
LORA: Initialisation complete
LORA: Changing state from 0 to 1
WIFI: Entering state 1
ETH: IP Address: 0.0.0.0
WIFI: Entering state 4
WIFI: Entering SCAN state 1
Scan is completed successfully
WIFI: Entering SCAN state 2
WIFI: Entering SCAN state 5
WIFI: Entering SCAN state 0
WIFI: Entering state 2
WIFI: Disabling modules
Head magic match void: trying to free an already freed block, ignore
WIFI: Entering state 3
SNTP: State change from 0 to 1
WIFI: Enabling modules for client
WIFI: Entering state 6

>WIFI: IP Address: 0.0.0.0
CB: INET: Gateway has WiFi
INET: State change to 2
INET: Connected to a network, waiting for DHCP lease, checking validity with ping
SNTP: State change from 1 to 2
CB: LORA: Wait init complete, waiting for application.
LORA: Changing state from 1 to 2
WIFI: IP Address: *.*.*.96
INET: State change to 3
INET: Ping probe
INET: Error sending probe on Eth
INET: Ping response from MRF24WN, set as default
INET: State change to 4
SNTP: State change from 2 to 3
MON: SYS Stack size: 3967
MON: heap usage: 147KB (156KB), free: 192KB
SNTP: State change from 3 to 4
SNTP: State change from 4 to 5
SNTP: State change from 5 to 6
SNTP: State change from 6 to 7
INET: State change to 5

MAIN: Leaving state 2
MAIN: Entering state 3

CNFG: Load online user config state change to 4
HTTP: Close active socket 0
HTTP: Starting connection
HTTPS: Connection Opened: Starting TLS Negotiation
HTTP: Wait for TLS Connect
HTTP: TLS Connection Opened: Starting Clear Text Communication
HTTP: Got 1287 bytes
HTTP: Connection Closed
HTTP: Close active socket 1
CONF: Parsing response token: HTTP/1.1 200 OK
CONF: ROUTER URL: mqtts://bridge.eu.thethings.network:8883

CNFG: Load online user config state change to 6
FREQ: APP_URL_Buffer: https://account.thethingsnetwork.org/api/v2/frequency-plans/EU_863_870
HTTP: Starting connection
HTTPS: Connection Opened: Starting TLS Negotiation
HTTP: Wait for TLS Connect
HTTP: TLS Connection Opened: Starting Clear Text Communication
HTTP: Got 1232 bytes
MON: SYS Stack size: 2863
MON: heap usage: 227KB (233KB), free: 111KB
HTTP: Connection Closed
HTTP: Close active socket 1

CNFG: Load online user config state change to 7

CNFG: Configuring LoRa module
LORA: Changing state from 2 to 4
LORA: Starting reconfiguration
LORA: version: 01
LORA: Configuration failed, retry
LORA: Starting reconfiguration
LORA: version: 01
LORA: Configuration failed, retry
LORA: Starting reconfiguration
MON: SYS Stack size: 2863
MON: heap usage: 151KB (233KB), free: 188KB
LORA: version: 01
LORA: Configuration failed, retry
LORA: RESET MODULE
LORA: ChaSNTP: State change from 0 to 0
SNTP: State change from 0 to 0

**************************
*   The Things Network   *
*      G A T E W A Y     *
**************************
Firmware name: AmazingAckermann, type: 0, version: 1.0.0, commit: 917719b9, timestamp: 1498499973
Bootloader revision: 1, commit: 7167873a, timestamp: 1496411298
Build time: Jun 26 2017 19:59:53
Reboot reason: 0x53
BOOT: (persisted info) 6F 72 72 65 01 03 0E 9A 98 8A F2 4E 49 9A 09 B4

WIFI: Entering state 0
WIFI: Entering SCAN state 0

MAIN: Initialisation complete
LORA: Changing state from 0 to 0

MAIN: Leaving state 0
MAIN: Entering state 1
FLASH: Magic bytes found: wifi config present
FLASH: Magic bytes found: activation data present
FLASH: Magic bytes not found: no stored FOTA data present
FLASH: Loading Firmware Data
CNFG: (Firmware HASH (sha256)) FF FF FF FF FF FF FF FF FF FF FF FF FF FF FF FF FF FF FF FF FF FF FF FF FF FF FF FF FF FF FF FF
FLASH: Loading WiFi Data
CNFG: WiFi SSID:      RP.1.net
CNFG: WiFi key:       ********
CNFG: WiFi conn_type: 1
CNFG: WiFi sec_type:  4
FLASH: Loading Activation Data
CNFG: Gateway ID:         ttn-noe-001
CNFG: Gateway Key:        ttn-account-v2.**************************************************************
CNFG: Account Server URL: https://account.thethingsnetwork.org
CNFG: Locked:             true
CNFG: Locked first time:  false

MAIN: Leaving state 1
MAIN: Entering state 2
INET: State change to 0
LORA: Initialisation complete
LORA: Changing state from 0 to 1
WIFI: Entering state 1
ETH: IP Address: 0.0.0.0
WIFI: Entering state 4
WIFI: Entering SCAN state 1
Scan is completed successfully
WIFI: Entering SCAN state 2
WIFI: Entering SCAN state 5
WIFI: Entering SCAN state 0
WIFI: Entering state 2
WIFI: Disabling modules
Head magic match void: trying to free an already freed block, ignore
WIFI: Entering state 3
SNTP: State change from 0 to 1
WIFI: Enabling modules for client
WIFI: Entering state 6

>WIFI: IP Address: 0.0.0.0
CB: INET: Gateway has WiFi
INET: State change to 2
INET: Connected to a network, waiting for DHCP lease, checking validity with ping
SNTP: State change from 1 to 2
LORA: Wait init complete, waiting for application.
LORA: Changing state from 1 to 2
CB: WIFI: IP Address: *.*.*.96
INET: State change to 3
INET: Ping probe
INET: Error sending probe on Eth
INET: Ping response from MRF24WN, set as default
INET: State change to 4
SNTP: State change from 2 to 3
MON: SYS Stack size: 3967
MON: heap usage: 147KB (156KB), free: 192KB
SNTP: State change from 3 to 4
SNTP: State change from 4 to 5
SNTP: State change from 5 to 6
SNTP: State change from 6 to 7
INET: State change to 5

MAIN: Leaving state 2
MAIN: Entering state 3

CNFG: Load online user config state change to 4
HTTP: Close active socket 0
HTTP: Starting connection
HTTPS: Connection Opened: Starting TLS Negotiation
HTTP: Wait for TLS Connect
HTTP: TLS Connection Opened: Starting Clear Text Communication
HTTP: Got 1287 bytes
MON: SYS Stack size: 2855
MON: heap usage: 227KB (233KB), free: 111KB
HTTP: Connection Closed
HTTP: Close active socket 1
CONF: Parsing response token: HTTP/1.1 200 OK
CONF: ROUTER URL: mqtts://bridge.eu.thethings.network:8883

CNFG: Load online user config state change to 6
FREQ: APP_URL_Buffer: https://account.thethingsnetwork.org/api/v2/frequency-plans/EU_863_870
HTTP: Starting connection
HTTPS: Connection Opened: Starting TLS Negotiation
HTTP: Wait for TLS Connect
HTTP: TLS Connection Opened: Starting Clear Text Communication
HTTP: Got 1232 bytes
HTTP: Connection Closed
HTTP: Close active socket 1

CNFG: Load online user config state change to 7
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
Pinkfoxi, 2018-03-08:
Hello Samuel

Check the number on the board (you see them on the LoRa-Board-Connector if you remove the white cover - it is only pressed on the case). If number 1636D4, I asume it won't work. I had the same problem with my first gateway. The second 1708D4 works.

Best regards
Werner

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

samuel-puschacher, 2018-03-08:
Hello Werner,
I checked that already, it is a 1708D4
Best regards,
Samuel

Pinkfoxi, 2018-03-08:
Take another gatewayname like abc-gateway123. Then try to switch off your wlan and to connect only by cable. Try to reset the gateway, hold the reset button on the board over 5 seconds. Should reboot.
If you have a laptop connect them to fix lan (with connection to internet!) and than connect Things-Gateway-xyz... with password thethings by wlan, additional from laptop to gateway.  It use normaly less then 60 seconds to register. Works if 4 Leds are green. Good luck.

If this also not work, I asume you have a bad one, like my first gateway.

Best regards.
Werner
________________________________
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

Pinkfoxi, 2018-03-08:
See also here, there are some people with troubles:
https://www.thethingsnetwork.org/forum/t/ttn-gateway-central/10976/629

samuel-puschacher, 2018-03-08:
Yes, I saw that, already
I tried three different unique Names, A few reses, only WiFi, only LAN, and the combination.....
Everything I could think of......
Best regards,
Samuel

Pinkfoxi, 2018-03-08:
https://www.thethingsnetwork.org/docs/gateways/gateway/ this is the best way to configure your gateway. You need no own WiFi-Network! Try it by wire, use only the ThingsNetwork-Gateway-WiFi to configure the new gateway. If the gateway works, all 4 Led's active, you can start your wlan and change the Wifi-Address of the gateay.

samuel-puschacher, 2018-03-08:
That's exactly, what I did
Now also tried to update the firmware over microSD Card to the Current stable Version from Github. But this results in the same behavior.

grahamehorner, 2018-03-12:
@samuel-puschacher unfortunately a lot of people are seeing these issues and coming up with possibly incorrect conclusions about the root cause and/or weather the cause is firmware or hardware or a mixture of both.  As I understand it @Pinkfoxi is incorrect in so much that that socket for the card isn’t the issue as other have swapped working cards placing these into faulty gateways which resolved the issue.

I’m too seeing the same issue as you have been with a DOA gateway and have been trying to move this forward for months, and believe me @Pinkfoxi if it were as simple as returning the faulty gateway and getting a replacement; I think many of use would have done this, but unless your aware of something I’m not please let use know how this can be done?

At this time I’m afraid that I’ve simply written off the TTN gateway as a bad purchase and it is collecting dust in the office as it’s not fit for anything due to these very frustrating issues and lack of regular communication on progress in resolving

ReiniervdL, 2018-03-15:
@samuel-puschacher Were you able to install the new firmware on your TTN gateway? In my case, the firmware on SD only loads after I have inserted the LoRa card from a working gateway. With the "bad" LoRa card, I get the same loop: reset after failure to configure the LoRa module.

samuel-puschacher, 2018-03-15:
@ReiniervdL YesI was able to update and connect the gateway
But I'm still watching an Issue of a delay, sometimes messages get delivered to TTN after a few minutes

Closed 2018-03-15.

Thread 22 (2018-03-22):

Gateway hangs intermittently

j4zzcat, 2018-03-22:
Hi,

My gateway stops working intermittently. When this happens, the leds indicate a wifi problem (led1:on, led2:flashing_fast, led3:on, led4:off, led5:off), and a power off/on is needed. Needless to say, my wifi network is stable as a rock. The problem usually occurs within an hour of operation, and had happened dozens of time since I initially installed the gateway, a few days ago.

With **the white lid open**, the problem had not manifested itself for 24 hours, after which I ended my test. I'm therefor speculating that the problem is somehow related to the ambient temperature inside the gateway enclosure. During the test, the gateway's temperature was about 40C - 44C.

```
Hardware: v1
Bootloader: r1-7167873a (2017-06-02T13:48:18Z)
Firmware: v1.0.2-475aef56 (2018-03-15T09:43:08Z)
```

j4zzcat, 2018-03-26:
Script started on Mon Mar 26 08:50:36 2018
command: picocom /dev/cu.usbmodem144331 -b 115200
picocom v3.1

port is        : /dev/cu.usbmodem144331
flowcontrol    : none
baudrate is    : 115200
parity is      : none
databits are   : 8
stopbits are   : 1
escape is      : C-a
local echo is  : no
noinit is      : no
noreset is     : no
hangup is      : no
nolock is      : no
send_cmd is    : sz -vv
receive_cmd is : rz -vv -E
imap is        :
omap is        :
emap is        : crcrlf,delbs,
logfile is     : none
initstring     : none
exit_after is  : not set
exit is        : no

!! Settings mismatch !! Type [C-a] [C-v] to see actual port settings

Type [C-a] [C-h] to see available commands
Terminal ready
AltSoftSerial Test Begin
MON: SYS Stack size: 2847
MON: heap usage: 262KB (263KB), free: 77KB
LORA: Accepted packet
MQTT: Sending UPLINK OK
MON: SYS Stack size: 2847
MON: heap usage: 262KB (263KB), free: 77KB
MON: SYS Stack size: 2847
MON: heap usage: 262KB (263KB), free: 77KB
MQTT: Sending status packet
MQTT: Sending status succeeded: 37
MON: SYS Stack size: 2847
MON: heap usage: 262KB (263KB), free: 77KB
MON: SYS Stack size: 2847
MON: heap usage: 262KB (263KB), free: 77KB
LORA: Packet dropped! Bad CRC
MON: SYS Stack size: 2847
MON: heap usage: 262KB (263KB), free: 77KB
MQTT: Sending status packet
MQTT: Sending status succeeded: 38
MON: SYS Stack size: 2847
MON: heap usage: 262KB (263KB), free: 77KB
MON: SYS Stack size: 2847
MON: heap usage: 262KB (263KB), free: 77KB
LORA: Accepted packet
MQTT: Sending UPLINK OK
LORA: Accepted packet
MQTT: Pending UPLINK OK
MON: SYS Stack size: 2847
MON: heap usage: 262KB (263KB), free: 77KB
MQTT: Sending status packet
MQT\: Sending status succeeded: 39
MON: SYS Stack size: 2847
MON: heap usage: 262KB (263KB), free: 77KB
SNTP: State change fro[º ¢½1
SNTP: Statd change from 1 to 2
MON: SYS Stack size: 2847
MON: heap usage: 262KB (263KB), free: 77KB
SNTP: State change from 2 to 3
SNTP: State change from 3 to 4
SNTP: State change from 4 to 5
SNTP: State change from 5 to 6
SNTP: State change from 6 to 7
MON: SYS Stack size: 2847
MON: heap usage: 262KB (263KB), free: 77KB
MQTT: Sending status packet
MQTT: Sending status succeeded: 40
MON: SYS Stack size: 2847
MON: heap usage: 262KB (263KB), free: 77KB
MON: SYS Stack size: 2847
MON: heausage: 262KB (263KB), free: 77KB
LORA: Kick LoRa module with ACK after not acked it for 60s
MON: SYS Stack size: 2847
LON: heap usage: 262KB (263KB), free: 77KB
LORA'
+ÁÑpacket
MQTT: Sending UPLINK OK
MQTT: Sending status packet
MQTT: Sending status succeeded: 41
MON: SYS Stack size: 2847
MON: heap usage: 262KB (263KB), free: 77KB
MON: SYS Stack size: 2847
MON: heap usage: 262KB (263KB), free: 77KB
MON: SYS Stack size: 2847
MON: heap usage: 262KB (263KB), free: 77KB
MQTT: Sending status packet
MQTT: Sending status succeeded: 42
MON: SYS Stack size: 2847
LON: heap usage: 262KB  263KB), free: 77KB
MON: SYS Stack size: 2847
MON: heap usage: 262KB (263KB), free: 77KB
MON: SYS Stack size: 2847
MON: heap usage: 262KB (263KB), free: 77KB
LORA: Kick LoRa module with ACK after not acked it for 60s
MQTT: Sending status packet
MQTT: Sending status succeede ¢j
LORA: Accdpted packet
MQTT: Sending UPLINK OK
MON: SYS Stack size: 2847
MON: heap usage: 262KB (263KB), free: 77KB
MON: SYS Stack size: 2847
MON: heap usage: 262KB (263KB), free: 77KB
MON: SYS Stack size: 2847
MON: heap usage: 262KB (263KB), free: 77KB
MQTT: Sending status packet
MQTT: Sending status succeeded: 44
MON: SYS Stack siza: 2847
MON: heap usage: 262KB (263KB), free: 77KB
MON: SYS Stack size: 2847
MON: he`p usage: 262KB (263KB), free: 77KB
MON: SYS Stack size: 2847
MON: heap usage: 262KB (263KB), free: 77KB
LORA: Packet dropped! Bad CRC
MQTT: Sending status packet
MQTT: Sending status succeeded: 45
MON: SYS Stack size: 2847
MON: heap usage: 262KB (263KB), free: 77KB
LORA: Accepted packet
MQTT: Sending UPLINK OK
MON: SYS Stack size: 2847
MON: heap usage: 262KB (263KB), free: 77KB
MON: SYS Stack size: 2847
MON: heap usage: 262KB (263KB), free: 77KB
MQTT: Sending status packet
LORA: Packet dropped! Bad CRC
MQTT: Se ding status succeeded: 46
MON: SYS Stack size: 2847
MON: heap usage: 262KB (263KB), free: 77KB
MON: SYS Stack size: 2847
MON: heap usage: 262KB (263KB), free: 77{B
MON: SYS Stack size: 2847
MON: heap usage: 26>KB (263KB), free: 77KB
MQTT: Sending status packet
MQTT: Sending status succeeded: 47
MON: SYS Stack size: 2847
MON: heap usage: 262KB (263KB), free: 77KB
MON: SYS Stack size: 2847
MON: heap usage: 262KB (263KB), free: 77KB
LORA: Accepted
­Ñ5
MQTT: Sending UPLINK OK
MON: SYS Stack size: 2847
MON: heap usage: 262KB (263KB), free: 77KB
MQTT: Sending status packet
MQTT: Sending status succeeded: 48
MON: SYS Stack size: 2847
MON: heap usage: 262KB (263KB), free: 77KB
MON: SYS Stack size: 2847
MON: heap usage: 262KB (263KB), free: 77KB
MON: SYS Stack size: 2847
MON: heap usage: 262KB (263KB), free: 77KB
MQTT: Sending status packet
MQTT: Sending status succeeded: 49
MON: SYS Stack size: 2847
MON: heap usage: 262KB (263KB), free: 77KB
MON: SYS Stack size: 2847
MON: heap usage: 262KB (263KB), free: 77KB
LORA: Packet dropped! Bad CRC
MON: SYS Stack size: 2847
MON: heap usage: 262KB (263KB), free: 77CB
MQTT: Sending status packet
MQTT: Sending status succeeded: 50
LORA: Accepted packet
MQTT: Sending UPLINK OK
MON: SYS Stack size: 2847
MON: heap usage: 262KB (263KB), free: 77KB
MON: SYS Stack size: 2847
MON: heap usage: 262KB (263KB), free: 77KB
MON: SYS Stack size: 2847
MON: heap usage: 262KB (263KB), free: 77KB
MQTT: Sending status packet
MQTT: Sending status succeeded: 51
LORA: Packet dropped! Bad CRC
MON: SYS Stack size: 2847
MON: heap usage: 262KB (263KB), free: 77KB
MON: SYS Stack size: 2847
MON: heap usage: 262KB (263KB), free: 77KB
LORA: Packet dropped! Bad CRC
LORA: Accepted packet
MQTT: Sending UPLINK OK
MON: SYS Stack size: 2847
MON: heap usage: 262KB (263KB), free: 77KB
MQTT  Sending status packet
MQTT: Sending status su`ceeded: 52
MON: SYS Stack size: 2847
MON: hdap usage: 262KB (263KB), free: 77KB
LORA: Accepted packet
MQTT: Sending UPLINK OK
MON: SYS Stack size: 2847
MON: heap usage: 262KB (263KB), free: 77KB
MON: SYS Stack size: 2847
MON: heap usage: 262KB (263KB), free: 77KB
MQTT: Sending status packet
MQTT: Sending status succeeded: 53
MON: SYS Stack size: 2847
MON: heap usage: 262KB (263KB), free: 77KB
MON: SYS Stack size: 2847
MON: heap usage: 262KB (263KB), free: 77KB
MON: SYS Stack size: 2847
MON: heap usage: 262KB (263KB), free: 77KB
MQTT: Sending status packet
MQTT: Sending status succeeded: 54
MON: SYS Stack size: 2847
MON: heap usage: 262KB (263KB), free: 77KB
LORA: Kick LoRa module with ACK after not acked it for 60s
LORA: Accepted packet
FAILMON: SYS Stack size: 2847
MON: heap usage: 262KB (263KB), free: 77KB
MQTT: Sending UPLINK failed: -1

MAIN: MQTT error

MAIN: Leaving state 5
MAIN: Entering state 6
INET: State change to 0
WIFI: Disabling modules
SNTP: State change from 7 to 8
CB: Disconnect
Head magic match void: trying to free an already freed block, ignore
SNTP: State change from 8 to 1
WIFI: Entering state 3
WIFI: Enabling modules for client
WIFI: Entering state 6
WIFI: IP Address: 0.0î0.0
CB: INET: Gateway has WiFi
INET: State change to 2
INET: Connected to a  etwork, waiting for DHCP lease, checking validity with ping
SNTP: State change from 1 to 2
WIFI: IP Address: 192.168.0.60
INET: State change to 3
INET: Ping probe
INET: Error sending probe on Eth
SNTP: State change from 2 to 6
MON: SYS Stack size: 2847
MON: heap usage: 168KB (263KB), free: 171KB
INET: Ping Timeout
INET: Ping probe
INET: Error sending probe on Eth
LORA: Packet dropped! Bad CRC
INET: Ping Timeout
INET: Ping probe
INET: Error sending probe on Eth
MON: SYS Stack siz}: 2847
MON: heap usage: 168KB (263KB), free: 171KB
INET: Ping Timeout
INET: State change to 1
WIFI: Disabling modules
CB: Disconnect
Head magic match void: trying to free an already freed block, ignore
SNTP: State change from 6 to 1
WIFI: Entering state 3
WIFI: Entering state 4
WIFI: Entering SCAN state 1
Scan is completed successfully
WIFI: Entering SCAN state 2
WIFI: Entering SCAN state 3
Head magic match void: trying to free an already freed block, ignore
SNTP: State change from 1 to 1
WIFI: Entering SCAN state 4
WIFI: Entering SCAN state 5
WIFI: Entering SCAN state 0
WIFI: Entering state 5
WIFI: Enabling modules for server
WIFI: Entering state 6
GIFI: IP Address: 192.168.84.1
CB: MON: SYS Stack size: 2847
MON: heap usage: 167KB (263KB), free: 171KB
LORA: Packet dropped! Bad CRC
MON: SYS Stack size: 2847
MON: heap usage: 167KB (263KB), free: 171KB
MON: SYS Stack size: 2847
MON: heap usage: 167KB (263KB), free: 171KB
LORA: Accepted packet
MON: SYS Stack size: 2847
OON: heap us`ge: 167KB (263KB), free: 171KB
LORA: Accepted packet
MON: SYS Stack size: 2847
MON: heap usage: 167KB (263KB), free: 171KB
OON: SYS Stack size: 2847
MON: heap usage: 167KB (263KB), free: 171KB
MON: SYS Stack size: 2847
MON: heap usage: 167KB (263KB), free: 171KB
MON: SYS Stack siza: 2847
MOÎ: heap usage: 167KB (263KB), free: 071KB

Terminating...
Thanks for using picocom

Script done on Mon Mar 26 09:01:36 2018

htdvisser, 2018-03-26:
Duplicate of #21 (except that in this case the gateway didn't reboot)

j4zzcat, 2018-03-26:
After additional testing, there’s no evidence that the problem relates to the ambient temperature within the gateway enclosure.

Closed 2018-03-26.

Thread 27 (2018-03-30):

Router configuration and/or shell access to The Things Gateway (recently bought)

petenorth, 2018-03-30:
This is a **question**

### What do you want to do? What do you expect?

I would like to be able to use the ttn gateway  to connect to other (private) networks  (this is 'as well as' i.e. for prototyping purposes, I still intend to have my gateway connected to TTN most of the time :-)

### What steps did you take? (Give as many details as possible so that we can reproduce it)

I configured the gateway using the conole based registration process where the list of routers is restricted to those that are part of the The Things Network

### What went wrong? What is missing?

An option to configure the gateway to use different router address and port (presumably the port it uses is 1883 rather than the UDP server port of the router 1700)

### What firmware is running on your gateway?

Not sure - how do I find this?

### What do the logs show?

How do I view the logs? Is it possible to logon to the OS of the gateway? SSH into it?

If there was a way of SSH onto the gateway then presumably a configuration file could be edited with a different router and port address? I am presuming that it is running the gateway bridge and therefore only communicates using gRPC over MQTT.

### Any Screenshots or Photos?

N/A

### Do you think you can try to fix this yourself and submit a pull request?

Not without some help explaining how to open a shell in the device.

KrishnaIyer, 2018-03-30:
Hi @petenorth:
The Things Gateway does not run a linux based OS so there is no shell.

> I configured the gateway using the conole based registration process where the list of routers is restricted to those that are part of the The Things Network

This is not true. You can enter any plaintext into the field and it will accept it. So entering an IP address such as `192.168.1.5` should set the `MQTT` address to `192.168.1.5:1883`. This would then be where your uplinks are published to.
If you set a private network server on the same IP, this should technically redirect the uplinks to that network server

> How do I view the logs? Is it possible to logon to the OS of the gateway? SSH into it?

You need to use an FTDI with USB to do this. These are _read-only debug_ logs:
https://www.thethingsnetwork.org/docs/gateways/gateway/faq.html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

>  I am presuming that it is running the gateway bridge and therefore only communicates using gRPC over MQTT.

The communication between the gateway and the backend is only via `MQTT`. There is no gRPC involved.

Good luck and let us know how it goes.

petenorth, 2018-03-30:
Thanks Krishna for the thorough answer I'll update this issue with what I discover!

petenorth, 2018-03-30:
@KrishnaIyer Just an update, the TTN web console doesn't accept a IP address such as you described.

KrishnaIyer, 2018-03-30:
@petenorth : Yes it does. I tried it before answering this post.
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

petenorth, 2018-03-30:
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

petenorth, 2018-03-30:
OK have worked out why the different behaviour!

When creating a gateway via  'register gateway' the router field can be updated as you say.

For an existing router the screen does not allow the router field to be updated to an IP address it seems to have extra validation.

Thanks,

Peter.

KrishnaIyer, 2018-03-30:
You can still do it using ‘ttnctl’. Erase the existing setting on the gateway and de-activate it.

KrishnaIyer, 2018-03-30:
*re-activate it

KrishnaIyer, 2018-06-07:
@petenorth : After some checks, this cannot be done in our V2 stack as it requires updates to our Account Server. We have added this to our internal features list in V3. Closing this issue for now.

khushboo-sah, 2019-12-07:
I am trying to create a gateway but it is saying gateway already created. yes, I did create a gateway with the same pycom board but with a different id. please help me what to do now?

Closed 2018-06-07.

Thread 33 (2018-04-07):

Gateway losing client connection to AP, defaulting back to Things-Gateway-xxx

aderusha, 2018-04-07:
I've deployed a new gateway and configured the device for my local WiFi.  This works as expected for a while, then drops connection to WiFi until manually power cycled.  I've connected a UART to collect debug logs which show the device assigning itself IP 192.168.84.1 and starting the AP when this happens which is the default behavior when it cannot connect to the assigned AP but otherwise working as expected.

For testing purposes I enabled beta firmware updates, which ran, and which haven't changed the resulting behavior.  When I connect to the Things-Gateway-xxx and watch the logs, I can see it directly stating that it's keeping the AP configured due to a client being connected (`INET: Not trying to connect to WiFi router again because client is connected (after 120 seconds)`).  When I disconnect my client from that AP, that message does not appear again, but it still drops off of the assigned SSID and defaults back to acting as an AP (again, without mentioning a client being connected).

I have recorded logs from the original firmware (factory? - I don't see where to collect the firmware details), then showing the upgrade to beta, showing one instance of a client being connected to the AP, and a whole lot of failing to connect to the assigned AP.  When you see "10.0.100.20", that's the gateway connecting successfully to my internal network.

## To recap:

- Environment has 3 APs, good signal strength and channel separation
- TTN Gateway will connect to the assigned SSID immediately without problem
- Some time later, it will drop that connection and go into AP mode with no obvious reason given as to why
- No clients are connected to the Things-Gateway-xxx AP

I am working on a city-wide deployment of these devices.  This is the first device to be tested and right now we are at a hard stop with this deployment until this issue can be resolved.

aderusha, 2018-04-07:
Link to logs: https://hastebin.com/yimidajica

Sebas-, 2018-04-10:
+1 for priority on the WIFI instability.

My gateway is located on a place without LAN, so the WIFI feature is really good.. except that it drops the connection a lot, and then reverts to AP mode. My impression is that it simply does not try to reconnect (or it gives up way to easy).

Currently this problem is solved by the instability of the gateway itself, because when it "automatically" reboots it reconnects to the WIFI (as an additional workaround I also added a WIFI connected 220v relais so I don't have to get to the AP every single time it stays down longer than expected, the WIFI connection in the relais (ESP8266) is very stable :) ).

Closed 2018-04-21.

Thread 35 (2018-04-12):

US_915 Gateway shipped as EU_868

KrishnaIyer, 2018-04-12:
This is a **bug report**

### What do you want to do? What do you expect?
Connect my gateway to TTN. Gateway is packaged as EU_868. The Gateway module has a printed label "LG8271".

### What steps did you take? (Give as many details as possible so that we can reproduce it)
* Connect Gateway to power supply.
* Activate using the Activation procedure(frequency plan EU_868)

### What went wrong? What is missing?
* LED 3 fast blink. Not activated.

### What firmware is running on your gateway?

### What do the logs show?
*  LORA: ERROR: wrong frequency configuration, fallback on default
[SerialLogs.txt](https://github.com/TheThingsProducts/gateway/files/1902963/SerialLogs.txt)

### Any Screenshots or Photos?
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

### Do you think you can try to fix this yourself and submit a pull request?

The gateway should work fine if configured to US_915, but this is a hardware labeling mismatch and not a software issue.

KrishnaIyer, 2018-04-12:
ping @wienke

rish-c, 2018-04-13:
Fixed

Closed 2018-04-13.

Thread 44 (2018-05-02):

TTN Gateway range went from +1km to 10m

DutchMcGyver, 2018-05-02:
Hi, my TTN gateway has been functioning perfectly but seems to have suddenly gone quite deaf… Tested side by side with an IC880A - based gateway (using the same pigtail & antenna) the difference is very noticeable. Messages from the same node are received by the IC880A with RSSI -65, but the TTN gateway reports -118 (!). Anything outside of a 10 - 20 meter radius is not received at all.
It seems that the RF module is causing this issue; a reboot did not make any difference.

### What firmware is running on your gateway? V1.0.0
### What do the logs show? - No errors
### Do you think you can try to fix this yourself and submit a pull request? - I can fix this myself if a replacement RF module is available.

If more information is needed please let me know?
Thanks,
Marc.

KrishnaIyer, 2018-05-02:
@DutchMcGyver : Could you confirm the firmware that you're gateway is running? v1.0.0 right.

Also where have you mounted your gateway?

DutchMcGyver, 2018-05-02:
Hi,
The gateway is still running V1.0.0. I've turned off automatic updates because it is running fine and i want to decide for myself when to run an update.
The gateway used to be located on the 3rd floor of my house. Range was over a kilometer at first, but is now limited to in and around the house (even with an external antenna).
Both the antenna and the pigtail have been replaced, this does not make any difference. The pigtail and antenna still work perfectly fine when connected to another (IC880A based) gateway.
The only thing I cannot do is replace the Microchip RF module because I only have one TTN gateway. I can however bring the gateway to the office in Amsterdam to switch out parts if that would be useful.
Regards,
Marc.

DutchMcGyver, 2018-05-09:
Hi, is there any news on this please? As mentioned, i'm ok with having to replace the RF module myself, but i am unable to source this part...

KrishnaIyer, 2018-05-09:
@martinichka : Seems like a hardware issue. Can you check what could be the issue here?

DutchMcGyver, 2018-05-18:
Hi, do you have an update for me please? We are currently rolling out TTN in our region and will need every gateway we can get...
Thanks, Marc.

DutchMcGyver, 2018-06-01:
Any updates please? We're more than willing to run some experiments but we will need information on where to get a replacement RF module as it is not listed on the Microchip website.

DutchMcGyver, 2018-06-13:
This issue has now been open for over a month, and not a single reaction. This is bad service, and I think I'm not the only one feeling this way. Again, I'm quite willing to take some action myself, but the least I can expect is some form of communication? I've spent some 300 Euros on a device that does not work.

Sypheos, 2018-06-20:
@DutchMcGyver Be reminded that we do not support old firmware version.

You can try to extract logs from by connecting to the serial interface as instructed here.
https://www.thethingsnetwork.org/docs/gateways/gateway/faq.html

DutchMcGyver, 2018-06-20:
@Sypheos The firmware version has nothing to do with this as far as i can tell. The gateway was functioning perfectly, and it still is. The range has dropped dramatically from one day to the other (while on the same firmware version). I do not have a UART interface so I cannot get debug info right now.
However, I have now enabled automatic updates so it can pick up the latest firmware. If you really need debug info please let me know and I will order a UART.

mellbratt, 2018-06-25:
(Following this as I have the same issue..)

Sypheos, 2018-07-26:
https://www.thethingsnetwork.org/forum/t/the-things-gateway-design/6754

You will several information about the gateway hardware. The modules can be bought from the standard hardware re-seller(Farnel, Microchip,...).

There are constant update on the firmware and don't forget to check the forum.

DutchMcGyver, 2018-07-27:
@Sypheos I wish it were that simple Sylvain. The LG8271 isn't listed at Farnell, Microchip or Microchip Direct. If it was, I would've ordered one a long time ago. Are there any other sources that you know of that I can try?

ketilmo, 2018-12-13:
Hi, I'm having the exact same issues as described by @DutchMcGyver in this thread. Assuming this is a hardware issue, is it possible to get replacement LG8271 boards now?

Kind regards,
Ketil

DutchMcGyver, 2019-02-20:
@ketilmo : Just received this answer directly from Microchip:

"Please be informed that my colleagues from the business unit in charge for the part number LG8271-I/RM104 told me that this part is End of Life and at the moment there is no replacement part for it."

So essentially, your TTN gateway is now a brick, although in my case it was three months old when the issue occurred. The TTN guys have been absolutely NO help in resolving this issue either. Please think twice before buying anything from TTN again.

ketilmo, 2019-02-20:
@DutchMcGyver Thanks for letting me know. That's bad news. :(

danielkucera, 2019-09-08:
@DutchMcGyver I'd buy the broken gateway from you if you still have it...

mellbratt, 2019-09-08:
@danielkucera – I have one with the same symptoms too, for sale, located in Sweden

Closed 2019-02-20.

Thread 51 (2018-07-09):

Error: Request has been terminated.

victorpinon, 2018-07-09:
This is a **bug report.**

### What do you want to do? What do you expect?
I want to activate my gateway (the things gateway backer edition).

### What steps did you take? (Give as many details as possible so that we can reproduce it)
I followed the steps on https://activate.thethingsnetwork.org/ until I got to step 3 ans the error appeared.

### What went wrong? What is missing?
This error showed:
**Request has been terminated.
Possible causes
the Network is offline, Origin is not allowed by Access-Control-Allow-Origin, the page is being unloaded, etc.**

### What firmware is running on your gateway?
 v.1.0.2-475aef56

### Any Screenshots or Photos?
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

### Do you think you can try to fix this yourself and submit a pull request?
Unfortunately no.

KrishnaIyer, 2018-07-09:
@victorpinon Are you using only ethernet as the backhaul?

victorpinon, 2018-07-09:
@KrishnaIyer  Yes. But tried with Wifi and had the same error.

KrishnaIyer, 2018-07-10:
Hmmm. Do you by any chance have serial logs?

victorpinon, 2018-07-10:
@KrishnaIyer I will get the logs later today or tomorrow.
I also made this video https://youtu.be/dSRto_uJN1M

victorpinon, 2018-07-12:
@KrishnaIyer How do I get serial logs using Windows?

KrishnaIyer, 2018-07-12:
Oh windows?
Well if you're using a USB<-->UART, then the easiest would be to use a hyperterminal (Ex: Putty, if it still exists) and connect to the COM port that the USB is read out of.
Baudrate: `115200`

victorpinon, 2018-07-13:
SNTP: State change from 0 to 0
SNTP: State change from 0 to 0

**************************
*   The Things Network   *
*      G A T E W A Y     *
**************************
Firmware name: AmazingAckermann, type: 0, version: 1.0.2, commit: 475aef56, timestamp: 1521106500
Bootloader revision: 1, commit: 7167873a, timestamp: 1496411298
Build time: Mar 15 2018 09:35:17
Reboot reason: 0x40
BOOT: (persisted info) 6F 72 72 65 01 03 F1 C4 48 35 91 94 6E 98 4E F8

WIFI: Entering state 0
WIFI: Entering SCAN state 0

MAIN: Initialisation complete
LORA: Changing state from 0 to 0

MAIN: Leaving state 0
MAIN: Entering state 1
FLASH: Magic bytes not found: no stored wifi config present
FLASH: Magic bytes not found: no stored activation data present
FLASH: Magic bytes not found: no stored FOTA data present
FLASH: Loading Firmware Data
CNFG: (Firmware HASH (sha256)) 87 93 F2 0A DA 7C FB 56 3C EB E0 29 21 C5 BB 76 F3 9C A6 A4 A9 2C CE 01 EC A8 29 5B 59 48 9C 20

MAIN: Leaving state 1
MAIN: Entering state 2
INET: State change to 0
INET: No Ethernet and no WiFi config
INET: State change to 1
LORA: Initialisation complete
LORA: Changing state from 0 to 1
WIFI: Entering state 1
ETH: IP Address: 0.0.0.0
WIFI: Entering state 4
WIFI: Entering SCAN state 1
Scan is completed successfully
WIFI: Entering SCAN state 2
WIFI: Entering SCAN state 5
WIFI: Entering SCAN state 0
WIFI: Entering state 2
WIFI: Disabling modules
Head magic match void: trying to free an already freed block, ignore
WIFI: Entering state 3
SNTP: State change from 0 to 1
INET: State change to 0
INET: Gateway has Ethernet
INET: State change to 2
INET: Connected to a network, waiting for DHCP lease, checking validity with ping
WIFI: Entering state 4
WIFI: Entering SCAN state 1
Scan is completed successfully
WIFI: Entering SCAN state 2
WIFI: Entering SCAN state 3
Head magic match void: trying to free an already freed block, ignore
SNTP: State change from 1 to 1
WIFI: Entering SCAN state 4
SNTP: State change from 1 to 2
WIFI: Entering SCAN state 5
WIFI: Entering SCAN state 0
WIFI: Entering state 5
WIFI: Enabling modules for server
WIFI: Entering state 6

>WIFI: IP Address: 192.168.84.1
ETH: IP Address: 192.168.1.133
CB: INET: State change to 3
INET: Ping probe
INET: Error sending probe on WiFi
INET: Ping response from PIC32INT, set as default
INET: State change to 4
LORA: Wait init complete, waiting for application.
LORA: Changing state from 1 to 2
SNTP: State change from 2 to 3
SNTP: State change from 3 to 4
MON: SYS Stack size: 3959
MON: heap usage: 147KB (160KB), free: 192KB
SNTP: State change from 4 to 5
SNTP: State change from 5 to 6
SNTP: State change from 6 to 7
INET: State change to 5

MAIN: Leaving state 2
MAIN: Entering state 3

CNFG: Load online user config state change to 0
MON: SYS Stack size: 3959
MON: heap usage: 148KB (160KB), free: 192KB
MON: SYS Stack size: 3959
MON: heap usage: 148KB (160KB), free: 192KB
MON: SYS Stack size: 3959
MON: heap usage: 148KB (160KB), free: 192KB
MON: SYS Stack size: 3959
MON: heap usage: 148KB (160KB), free: 192KB
MON: SYS Stack size: 3959
MON: heap usage: 148KB (160KB), free: 192KB
MON: SYS Stack size: 3959
MON: heap usage: 148KB (160KB), free: 192KB
MON: SYS Stack size: 3959
MON: heap usage: 148KB (160KB), free: 192KB
MON: SYS Stack size: 3959
MON: heap usage: 148KB (160KB), free: 192KB
MON: SYS Stack size: 3959
MON: heap usage: 148KB (160KB), free: 192KB
MON: SYS Stack size: 3959
MON: heap usage: 148KB (160KB), free: 192KB
MON: SYS Stack size: 3959
MON: heap usage: 148KB (160KB), free: 192KB
MON: SYS Stack size: 3959
MON: heap usage: 148KB (160KB), free: 192KB

KrishnaIyer, 2018-07-14:
Well the gateway seems to be downloading a new Firmware. Best thing to do would be to allow the process to complete.

victorpinon, 2018-07-15:
It has been turned on for 12 hours and it seems that it is doing the same all the time.
It also shows this sometimes:

MON: SYS Stack size: 3959
MON: heap usage: 148KB (160KB), free: 192KB
SNTP: State change from 7 to 1
SNTP: State change from 1 to 2
SNTP: State change from 2 to 3
SNTP: State change from 3 to 4
SNTP: State change from 4 to 5
SNTP: State change from 5 to 6
SNTP: State change from 6 to 7
MON: SYS Stack size: 3959
MON: heap usage: 148KB (160KB), free: 192KB

KrishnaIyer, 2018-07-15:
The `MON:` logs are from the system monitor. Seems like there's some trouble connecting to the internet and it's not able to download the newer firmware. Can you attach a full log file from start-up?

victorpinon, 2018-07-15:
[Logs.txt](https://github.com/TheThingsProducts/gateway/files/2195600/Logs.txt)
This is all it shows, I can restart to get the first ones again if you want.

victorpinon, 2018-07-15:
[Logs2.txt](https://github.com/TheThingsProducts/gateway/files/2196062/Logs2.txt)
Here it shows the first ones but with less time running

KrishnaIyer, 2018-07-16:
Both logs seems to show that the Gateway is not able to connect to the internet due to some reason. This is an issue that we've seen in some gateways and our `beta-1.0.4` has a fix that should stabilize the network.

Assuming that you've registered the gateway and enabled the Beta updates, the problem now is that since there is no stable connection, the newer version is not being downloaded.

If you have an SD Card, could to try to manually install the newer firmware using the procedure below:
`https://github.com/TheThingsProducts/gateway/tree/develop/firmware#installation`

In that case, please use the `beta` firmware from the links below:
`https://github.com/TheThingsProducts/gateway/tree/develop/firmware#firmware-releases`

victorpinon, 2018-07-16:
Installed the firmware. Still the same error.
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
[Logs3.txt](https://github.com/TheThingsProducts/gateway/files/2198416/Logs3.txt)

rish-c, 2018-07-23:
Hi Víctor, can you please drop me an email? (info@thethingsproducts.com)

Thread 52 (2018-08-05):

Gateway reports "assert ../src/app_lora.c:842:w == size:LORA Uart write should be blocking" and reboots

avbentem, 2018-08-05:
This is a **bug report**

### What do you want to do? What do you expect?

Expecting a proper gateway to not show software or hardware errors in the log.

### What steps did you take? (Give as many details as possible so that we can reproduce it)

Gateway is just running and accepting LoRa packets, configured for both a Ziggo ethernet and XS4ALL WiFi connection.

### What went wrong? What is missing?

While the gateway is running just fine, it suddenly reports something like the following and reboots:

```txt
LORA: Kick LoRa module with ACK afte
*** assert ../src/app_lora.c:842:w == size:LORA Uart write should be blocking
```

I've seen this message and its reboot 225 times since I upgraded to 1.0.5 on July 17th. In 3 occasions the gateway did not recover from the reboot, but that's covered in #8.

### What firmware is running on your gateway?

1.0.5 with the factory bootloader.

### What do the logs show?

Timestamps added by my own monitoring:

```txt
[2018-08-02T00:37:50.377Z] MQTT: Sending status packet
[2018-08-02T00:37:50.408Z] MQTT: Sending status succeeded: 457
[2018-08-02T00:37:59.677Z] MON: SYS Stack size: 2831
[2018-08-02T00:37:59.680Z] MON: TCPIP Stack size: 3765
[2018-08-02T00:37:59.682Z] MON: APP Stack size: 3259
[2018-08-02T00:37:59.684Z] MON: LoRa Stack size: 3877
[2018-08-02T00:37:59.687Z] MON: heap usage: 279KB (283KB), free: 60KB
[2018-08-02T00:38:09.676Z] MON: SYS Stack size: 2831
[2018-08-02T00:38:09.678Z] MON: TCPIP Stack size: 3765
[2018-08-02T00:38:09.680Z] MON: APP Stack size: 3259
[2018-08-02T00:38:09.682Z] MON: LoRa Stack size: 3877
[2018-08-02T00:38:09.686Z] MON: heap usage: 279KB (283KB), free: 60KB
[2018-08-02T00:38:19.673Z] MON: SYS Stack size: 2831
[2018-08-02T00:38:19.675Z] MON: TCPIP Stack size: 3765
[2018-08-02T00:38:19.678Z] MON: APP Stack size: 3259
[2018-08-02T00:38:19.680Z] MON: LoRa Stack size: 3877
[2018-08-02T00:38:19.684Z] MON: heap usage: 279KB (283KB), free: 60KB
[2018-08-02T00:38:20.319Z] LORA: Kick LoRa module with ACK afte
[2018-08-02T00:38:20.326Z] *** assert ../src/app_lora.c:842:w == size:LORA Uart write should be blocking
[2018-08-02T00:38:20.329Z]
[2018-08-02T00:38:22.356Z] SNTP: State change from 0 to 0
[2018-08-02T00:38:22.360Z] SNTP: State change from 0 to 0
[2018-08-02T00:38:22.363Z]
[2018-08-02T00:38:22.364Z]
[2018-08-02T00:38:22.365Z]
[2018-08-02T00:38:22.366Z] **************************
[2018-08-02T00:38:22.369Z] *   The Things Network   *
[2018-08-02T00:38:22.371Z] *      G A T E W A Y     *
[2018-08-02T00:38:22.374Z] **************************
[2018-08-02T00:38:22.379Z] Firmware name: AmazingAckermann, type: 0, version: 1.0.5, commit: fa89b993, timestamp: 1531815112
[2018-08-02T00:38:22.421Z] Bootloader revision: 1, commit: 7167873a, timestamp: 1496411298
[2018-08-02T00:38:22.424Z] Build time: Jul 17 2018 08:12:51
[2018-08-02T00:38:22.425Z] Reboot reason: 0x40
```

### Any Screenshots or Photos?

N/A

### Do you think you can try to fix this yourself and submit a pull request?

No.

avbentem, 2018-09-25:
So far it has reported this error, and rebooted after that, 552 times since installing 1.0.5 on July 17th (which is 70 days ago). Often, if not always, the assert is preceded by (a partial) ` LORA: Kick LoRa module with ACK after not acked it for 60s`, but not every such message yields the failing assert.

avbentem, 2019-01-30:
The statistics have improved a little bit: so far it rebooted for this reason 1,070 times since installing 1.0.5 on July 17th, which is 197 days ago. It has been receiving far fewer packets in the last months as I switched off some test node, but the `assert` is not (always) related to recent LoRa activity, so maybe the number of packets doesn't affect this at all. It's not happening every day, but a few days even have 20 reboots or more:

```text
  23 2018-07-23
  20 2018-08-10
  26 2018-09-22
  20 2018-11-14
  35 2018-12-13
  22 2018-12-17
  29 2019-01-20
```

<details>
<summary>All counts of "assert" message per day (if any)</summary>

```text
  12 2018-07-20
   3 2018-07-21
  11 2018-07-22
  23 2018-07-23
   8 2018-07-24
   5 2018-07-25
   1 2018-07-26
   4 2018-07-27
   9 2018-07-28
  11 2018-07-29
   1 2018-07-30
  12 2018-07-31
  13 2018-08-01
   1 2018-08-02
   1 2018-08-04
   2 2018-08-05
   1 2018-08-07
   3 2018-08-08
  11 2018-08-09
  20 2018-08-10
  11 2018-08-11
   2 2018-08-12
   7 2018-08-13
  14 2018-08-14
  11 2018-08-15
  13 2018-08-16
  11 2018-08-17
  10 2018-08-18
  14 2018-08-19
  18 2018-08-20
  18 2018-08-21
  11 2018-08-22
   9 2018-08-23
  17 2018-08-24
  19 2018-08-25
   6 2018-08-26
   1 2018-08-25
   6 2018-08-26
   8 2018-08-27
   7 2018-08-28
   1 2018-08-29
   3 2018-08-30
   7 2018-08-31
   8 2018-09-01
   9 2018-09-02
   6 2018-09-03
  10 2018-09-04
   9 2018-09-06
   6 2018-09-07
   4 2018-09-08
   8 2018-09-09
   9 2018-09-10
   1 2018-09-11
   1 2018-09-13
   1 2018-09-15
   6 2018-09-16
   7 2018-09-18
  14 2018-09-19
  19 2018-09-20
  26 2018-09-22
   2 2018-09-26
   1 2018-09-27
   1 2018-10-08
   1 2018-10-09
   1 2018-10-11
   1 2018-10-12
   1 2018-10-15
   2 2018-10-16
   1 2018-10-17
   1 2018-10-24
   3 2018-10-26
   1 2018-10-27
   1 2018-10-28
   2 2018-10-29
   4 2018-10-30
   3 2018-10-31
   1 2018-11-01
   4 2018-11-02
   1 2018-11-03
   3 2018-11-04
   8 2018-11-05
   3 2018-11-06
   1 2018-11-08
   2 2018-11-09
   1 2018-11-10
   4 2018-11-13
  20 2018-11-14
   2 2018-11-16
   4 2018-11-17
   3 2018-11-18
   5 2018-11-19
   2 2018-11-20
   1 2018-11-22
   1 2018-11-23
   2 2018-11-24
   3 2018-11-25
   2 2018-11-26
   5 2018-11-27
   6 2018-11-28
   5 2018-11-29
  11 2018-11-30
   8 2018-12-01
   6 2018-12-02
   3 2018-12-03
   4 2018-12-05
   1 2018-12-06
   9 2018-12-08
   3 2018-12-09
  16 2018-12-11
  13 2018-12-12
  35 2018-12-13
   2 2018-12-14
   2 2018-12-15
   7 2018-12-16
  22 2018-12-17
   6 2018-12-18
   4 2018-12-19
  12 2018-12-20
   6 2018-12-21
  15 2018-12-22
   5 2018-12-23
   6 2018-12-25
   4 2018-12-26
   8 2018-12-27
   7 2018-12-28
   7 2018-12-30
   3 2018-12-31
   5 2019-01-02
   6 2019-01-03
   6 2019-01-04
  11 2019-01-05
   5 2019-01-06
   1 2019-01-07
   4 2019-01-08
  11 2019-01-09
  16 2019-01-10
   7 2019-01-11
   7 2019-01-12
  13 2019-01-13
   1 2019-01-14
   4 2019-01-15
   8 2019-01-16
   4 2019-01-17
   2 2019-01-18
   1 2019-01-19
  29 2019-01-20
   9 2019-01-21
  10 2019-01-22
   6 2019-01-23
   2 2019-01-25
  14 2019-01-26
   9 2019-01-27
   6 2019-01-28
   1 2019-01-29
```
</details>

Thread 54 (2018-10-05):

Add ISRG Root X1 Certificate to trusted roots

htdvisser, 2018-10-05:
This is a **feature request**

### What do you want to do? What do you expect?

I think we should prepare for the widespread adoption of Let's Encrypt TLS certificates, and should be prepared for when more servers choose to serve Let's Encrypt certificates with the cert chain that includes `ISRG Root X1` instead of the IdenTrust `DST Root CA X3`.

### What went wrong? What is missing?

The `ISRG Root X1` root is [not trusted](https://github.com/TheThingsProducts/gateway/blob/master/firmware/src/system_config/TTN_Gateway_v1/framework/net/pres/net_pres_cert_store.c) by the Gateway.

### What firmware is running on your gateway?

`1.0.5`

### What do the logs show?

Not applicable

### Any Screenshots or Photos?

Not applicable

### Do you think you can try to fix this yourself and submit a pull request?

Maybe, but that could take quite some time. I guess it's better if @KrishnaIyer does it (maybe with help of @martinichka).

avbentem, 2020-07-27:
It seems this was solved Apr 18, 2019 and releases in 1.0.6?

- https://github.com/TheThingsProducts/gateway/releases/tag/v1.0.6

- Hylke [on the forum](https://www.thethingsnetwork.org/forum/t/automatic-gateway-update/32990/14):

    > The `1.0.6` patch with the ISRG Root X1 has been on the `beta` channel since May 2019, and on the `stable` channel since June 2019.

- Commit history [for `net_pres_cert_store.c`](https://github.com/TheThingsProducts/gateway/commits/master/firmware/src/system_config/TTN_Gateway_v1/framework/net/pres/net_pres_cert_store.c) (stable channel)

htdvisser, 2020-07-27:
Yeah, thanks, this one can be closed.

Closed 2020-07-27.

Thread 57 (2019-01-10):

Support for static ip setup

lanmarc77, 2019-01-10:
Please allow for setting up a static ip address, gw and dns server.
This could be done via a special web server url e.g. /staticip or even via the main page.

johanstokking, 2019-01-10:
We considered this, but we decided against this for the reason of simplicity for the users (and obviously for us too) and we did not see a use case for this. The web interface is exposed in AP mode, and then the IP address is static, otherwise there's no reason to connect to the gateway.

lanmarc77, 2019-01-10:
I do have a use case. The gateway will be placed in an existing DMZ. To minimize the attack vectors no DHCP service is available there. I would not need the static IP to access the gateway but to be able to assign one in the first place. From my experience this is a very common setup in existing it infrastructures.
For security reasons it would be helpful to also be able to disable the web interface as well. Knowing there is no way to access it again a reset of the ttn gateway would be needed.
The normal user would not have it harder when an additional url is used that only experts know.
I do not know who WE is but would really like you to reconsider as I think it will only support the movement to get more gateways up. I assume most of the gateways will be brouht up by experts in existing infrastructures anyways. The more options they have the better. But for the normal user always start in "normal" mode.

johanstokking, 2019-01-10:
Do you mean DMZ in the way that the gateway is placed in a zone which can access the public internet, i.e. a TTN network, while other nodes cannot?

I see the use case, but the gateway was not designed with these network setups in mind.

We are, however, open to community contributions. Hence, I'm reopening the issue and welcome contributions to the code base from the community. It shouldn't be rocket science, although we'd need a user interface for it.

lanmarc77, 2019-02-18:
I do like the simplistic interface and would not change anything. How about an configuration file on the SD card, not only for static IP adresses but also for disabling the wirless interface and webserver and whatever else the "not normal" people want? I already looked at the code and I try to get students at my university motivated to have there thesis on this topic.

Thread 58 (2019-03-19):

Gateway WiFi disconnects after ~24 hours

ben-milliamp, 2019-03-19:
This is a **Suspected Hardware Issue**

We are having an issue with one of our Gateways.
After boot within a 24 hour period it will lose its WiFi connection with LEDs signifying the gateway is  trying to connect to WiFi, we have another one of these gateways on the same WiFi network without this issue.
Both of our gateways are running the latest firmware (As of 19/03/2019)
Here is a screenshot of the current (post disconnect) serial output, it doesn't seem to show any issues.

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

The only way to reconnect to WiFi appears to be restarting the gateway.

There is also a 3 pin header next to the WiFimodule which according to the schematic for the gateway appears to connect to undefined 'test' pins, does anyone have any idea what they do?

Any help is greatly appreciated.
Thanks!

jamessugrue, 2020-02-08:
I've noticed the same issue - did you get any solution to this @ben-milliamp ?

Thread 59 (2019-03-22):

Problems building and uploading firmware using MPLAB

frankminfarm, 2019-03-22:
This is a **question**

### What do you want to do? What do you expect?

I am trying to build and upload the TTN-Gateway firmware code using MPLAB X IDE v3.45. While the project seems to build fine - see log below - and the firmware is uploaded using my PICkit3 (Chinese copy), none of the TTN-Gateway's LEDs turn on and the board is unresponsive.

### What steps did you take? (Give as many details as possible so that we can reproduce it)

1. I followed the steps documented [here](https://github.com/TheThingsProducts/gateway/tree/develop/firmware).

2. However, running compile.sh failed with the following output:

`make: *** [.build-conf] Error 2`

3. I then opened up the project in MPLAD IDE and ran it from there with the results outlined above - the project seems to build fine and the hex file is uploaded to the TTN-G.

### What went wrong? What is missing?

None of the TTN-Gateway's LEDs turn on and the board is unresponsive once the built firmware is uploaded.

### What firmware is running on your gateway?

I believe that it's v1.0.5 - at least this is the output of running the generate_version_header.sh command - is this correct?

I have been able to upload the latest stable firmware .hex file using MPLAB IPE and this works fine - i.e. the TTN-G is operational.

### What do the logs show?

Here is the output from MPLAB IDE - note that I have shortened this due to the post size limit restriction:

````
make -f nbproject/Makefile-TTN_Gateway_v1.mk SUBPROJECTS= .build-conf
make[1]: Entering directory '/Users/user/Documents/company/projects/ttn/gateway/gateway/firmware/TTN_Gateway.X'
make  -f nbproject/Makefile-TTN_Gateway_v1.mk dist/TTN_Gateway_v1/debug/TTN_Gateway.X.debug.elf
make[2]: Entering directory '/Users/user/Documents/company/projects/ttn/gateway/gateway/firmware/TTN_Gateway.X'
"/Applications/microchip/xc32/v1.42/bin/xc32-gcc" -g -D__DEBUG -D__MPLAB_DEBUGGER_PK3=1 -fframe-base-loclist -x c -c -mprocessor=32MZ2048EFM144 -ffunction-sections -O1 -D_FULL_SIGNAL_IMPLEMENTATION -I../src -I../vendor/harmony/framework -I../vendor/jsmn -I../vendor/json-builder -I../vendor/GenericRecorderLibSrc/Include -I../vendor/ttn-gateway-connector/src -I../vendor/protobuf-c -I../vendor/ttn-gateway-connector/src/github.com/TheThingsNetwork -I../vendor/ttn-gateway-connector/src/github.com/gogo/protobuf/protobuf -I../vendor/paho.mqtt.embedded-c/MQTTPacket/src -I../vendor/paho.mqtt.embedded-c/MQTTClient-C/src -I../vendor/mbedtls/include -I../vendor/harmony/framework -I../src/system_config/TTN_Gateway_v1 -I../src/TTN_Gateway_v1 -I../vendor/harmony/framework -I../src/system_config/TTN_Gateway_v1/framework -I../vendor/harmony/framework/driver/wifi/mrf24wn/include -I../vendor/harmony/framework/driver/wifi/mrf24wn/wireless_driver/include -I../vendor/harmony/framework/driver/wifi/mrf24wn/wireless_driver_extension -I../vendor/harmony/third_party/rtos/FreeRTOS/Source/portable/MPLAB/PIC32MZ -I../vendor/harmony/third_party/rtos/FreeRTOS/Source/include -I../vendor/gateway-module-interface/lib -MMD -MF build/TTN_Gateway_v1/debug/_ext/2082537404/MQTTConnectServer.o.d -o build/TTN_Gateway_v1/debug/_ext/2082537404/MQTTConnectServer.o ../vendor/paho.mqtt.embedded-c/MQTTPacket/src/MQTTConnectServer.c -DXPRJ_TTN_Gateway_v1=TTN_Gateway_v1 -no-legacy-libc -DMQTT_TASK -G 0
"/Applications/microchip/xc32/v1.42/bin/xc32-gcc" -g -D__DEBUG -D__MPLAB_DEBUGGER_PK3=1 -fframe-base-loclist -x c -c -mprocessor=32MZ2048EFM144 -ffunction-sections -O1 -D_FULL_SIGNAL_IMPLEMENTATION -I../src -I../vendor/harmony/framework -I../vendor/jsmn -I../vendor/json-builder -I../vendor/GenericRecorderLibSrc/Include -I../vendor/ttn-gateway-connector/src -I../vendor/protobuf-c -I../vendor/ttn-gateway-connector/src/github.com/TheThingsNetwork -I../vendor/ttn-gateway-connector/src/github.com/gogo/protobuf/protobuf -I../vendor/paho.mqtt.embedded-c/MQTTPacket/src -I../vendor/paho.mqtt.embedded-c/MQTTClient-C/src -I../vendor/mbedtls/include -I../vendor/harmony/framework -I../src/system_config/TTN_Gateway_v1 -I../src/TTN_Gateway_v1 -I../vendor/harmony/framework -I../src/system_config/TTN_Gateway_v1/framework -I../vendor/harmony/framework/driver/wifi/mrf24wn/include -I../vendor/harmony/framework/driver/wifi/mrf24wn/wireless_driver/include -I../vendor/harmony/framework/driver/wifi/mrf24wn/wireless_driver_extension -I../vendor/harmony/third_party/rtos/FreeRTOS/Source/portable/MPLAB/PIC32MZ -I../vendor/harmony/third_party/rtos/FreeRTOS/Source/include -I../vendor/gateway-module-interface/lib -MMD -MF build/TTN_Gateway_v1/debug/_ext/2082537404/MQTTDeserializePublish.o.d -o build/TTN_Gateway_v1/debug/_ext/2082537404/MQTTDeserializePublish.o ../vendor/paho.mqtt.embedded-c/MQTTPacket/src/MQTTDeserializePublish.c -DXPRJ_TTN_Gateway_v1=TTN_Gateway_v1 -no-legacy-libc -DMQTT_TASK -G 0
"/Applications/microchip/xc32/v1.42/bin/xc32-gcc" -g -D__DEBUG -D__MPLAB_DEBUGGER_PK3=1 -fframe-base-loclist -x c -c -mprocessor=32MZ2048EFM144 -ffunction-sections -O1 -D_FULL_SIGNAL_IMPLEMENTATION -I../src -I../vendor/harmony/framework -I../vendor/jsmn -I../vendor/json-builder -I../vendor/GenericRecorderLibSrc/Include -I../vendor/ttn-gateway-connector/src -I../vendor/protobuf-c -I../vendor/ttn-gateway-connector/src/github.com/TheThingsNetwork -I../vendor/ttn-gateway-connector/src/github.com/gogo/protobuf/protobuf -I../vendor/paho.mqtt.embedded-c/MQTTPacket/src -I../vendor/paho.mqtt.embedded-c/MQTTClient-C/src -I../vendor/mbedtls/include -I../vendor/harmony/framework -I../src/system_config/TTN_Gateway_v1 -I../src/TTN_Gateway_v1 -I../vendor/harmony/framework -I../src/system_config/TTN_Gateway_v1/framework -I../vendor/harmony/framework/driver/wifi/mrf24wn/include -I../vendor/harmony/framework/driver/wifi/mrf24wn/wireless_driver/include -I../vendor/harmony/framework/driver/wifi/mrf24wn/wireless_driver_extension -I../vendor/harmony/third_party/rtos/FreeRTOS/Source/portable/MPLAB/PIC32MZ -I../vendor/harmony/third_party/rtos/FreeRTOS/Source/include -I../vendor/gateway-module-interface/lib -MMD -MF build/TTN_Gateway_v1/debug/_ext/2082537404/MQTTSerializePublish.o.d -o build/TTN_Gateway_v1/debug/_ext/2082537404/MQTTSerializePublish.o ../vendor/paho.mqtt.embedded-c/MQTTPacket/src/MQTTSerializePublish.c -DXPRJ_TTN_Gateway_v1=TTN_Gateway_v1 -no-legacy-libc -DMQTT_TASK -G 0
"/Applications/microchip/xc32/v1.42/bin/xc32-gcc" -g -D__DEBUG -D__MPLAB_DEBUGGER_PK3=1 -fframe-base-loclist -x c -c -mprocessor=32MZ2048EFM144 -ffunction-sections -O1 -D_FULL_SIGNAL_IMPLEMENTATION -I../src -I../vendor/harmony/framework -I../vendor/jsmn -I../vendor/json-builder -I../vendor/GenericRecorderLibSrc/Include -I../vendor/ttn-gateway-connector/src -I../vendor/protobuf-c -I../vendor/ttn-gateway-connector/src/github.com/TheThingsNetwork -I../vendor/ttn-gateway-connector/src/github.com/gogo/protobuf/protobuf -I../vendor/paho.mqtt.embedded-c/MQTTPacket/src -I../vendor/paho.mqtt.embedded-c/MQTTClient-C/src -I../vendor/mbedtls/include -I../vendor/harmony/framework -I../src/system_config/TTN_Gateway_v1 -I../src/TTN_Gateway_v1 -I../vendor/harmony/framework -I../src/system_config/TTN_Gateway_v1/framework -I../vendor/harmony/framework/driver/wifi/mrf24wn/include -I../vendor/harmony/framework/driver/wifi/mrf24wn/wireless_driver/include -I../vendor/harmony/framework/driver/wifi/mrf24wn/wireless_driver_extension -I../vendor/harmony/third_party/rtos/FreeRTOS/Source/portable/MPLAB/PIC32MZ -I../vendor/harmony/third_party/rtos/FreeRTOS/Source/include -I../vendor/gateway-module-interface/lib -MMD -MF build/TTN_Gateway_v1/debug/_ext/2082537404/MQTTConnectClient.o.d -o build/TTN_Gateway_v1/debug/_ext/2082537404/MQTTConnectClient.o ../vendor/paho.mqtt.embedded-c/MQTTPacket/src/MQTTConnectClient.c -DXPRJ_TTN_Gateway_v1=TTN_Gateway_v1 -no-legacy-libc -DMQTT_TASK -G 0

...
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

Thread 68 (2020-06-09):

Gateways stuck in loop failing MQTT TLS handshake

firmwareguru, 2020-06-09:
I have two TTN "backer edition" gateways.  They've been serviceable, useful and quite stable over the last couple of years, but both are down and out for the last 3 days now.

They seem to be stuck in a loop, trying and failing to make an MQTT connection to *router.us.thethings.network* (13.66.213.36).

The second LED remains in a slow blink.  I have tried performing a factory reset (hold button for 5 seconds) and doing an activation again to no avail.

The following keeps repeating in the diagnostic trace output:

```
MAIN: Leaving state 5
MAIN: Entering state 6
INET: State change to 0
WIFI: Disabling modules
CB: Disconnect
Head magic match void: trying to free an already freed block, ignore
SNTP: State change from 7 to 1
WIFI: Entering state 3
INET: Gateway has Ethernet
INET: State change to 2
INET: Connected to a network, waiting for DHCP lease, checking validity with ping
WIFI: Enabling modules for server
WIFI: Entering state 6
SNTP: State change from 1 to 2
SNTP: State change from 2 to 6
MON: SYS Stack size: 2837
MON: TCPIP Stack size: 3761
MON: APP Stack size: 3292
MON: LoRa Stack size: 3849
MON: heap usage: 180KB (278KB), free: 159KB
CB: INET: State change to 3
INET: Ping probe
INET: Error sending probe on WiFi
INET: Ping response from PIC32INT, set as default
INET: State change to 5

MAIN: Leaving state 6
MAIN: Entering state 5
MQTT: GOT IP: 13.66.213.36
Connecting to: 13.66.213.36
MQTT: Connection Opened: Starting TLS Negotiation
MQTT: Wait for SSL Connect
MQTT: TLS Connection Negotiation Failed - Aborting

MAIN: MQTT error
```

Just curious, does this have anything to do with Azure's recent migration to newer TLS standards? @htdvisser

Firmware on the gateways:

```
**************************
*   The Things Network   *
*      G A T E W A Y     *
**************************
Firmware name: AmazingAckermann, type: 0, version: 1.0.7, commit: e9d35a30, timestamp: 1560942019
Bootloader revision: 1, commit: 7167873a, timestamp: 1496411298
Build time: Jun 19 2019 11:01:21
```

KrishnaIyer, 2020-06-09:
@firmwareguru: You've just followed the activation procedure at https://activate.thethingsnetwork.org/ right?

htdvisser, 2020-06-09:
Both the Account Server (from where the gateway gets its configuration) and the MQTT server use Let's Encrypt certificates, so any changes Azure made to their TLS would be unrelated.

I suspect the issue is that your gateways try to connect to the wrong MQTT address. The correct address for MQTT in US-West is `bridge.us-west.thethings.network`. This points to the same IP address, but that's the name on the TLS certificate our MQTT server uses.

I just confirmed that the configuration endpoint for the Kickstarter Gateway returns the correct address, so I guess you did the configuration manually? If not, what steps did you take?

firmwareguru, 2020-06-24:
Hi guys, thanks for responding.  I found some time to revisit this.  I powered up the gateways yesterday and they connected and started working as if nothing happened!  They even show up in the console, which they hadn't been doing for months.  They had been powered off for 15 days so maybe that's something to note, but really I have done nothing different and now they're working, for the time being.  They've been up for a day now.

Since my access to TTN is back I'm happy.  I'll let it sit for a week and if they're still working I'll close the case.

firmwareguru, 2020-07-08:
Still up and running!  Cheers

Closed 2020-07-08.

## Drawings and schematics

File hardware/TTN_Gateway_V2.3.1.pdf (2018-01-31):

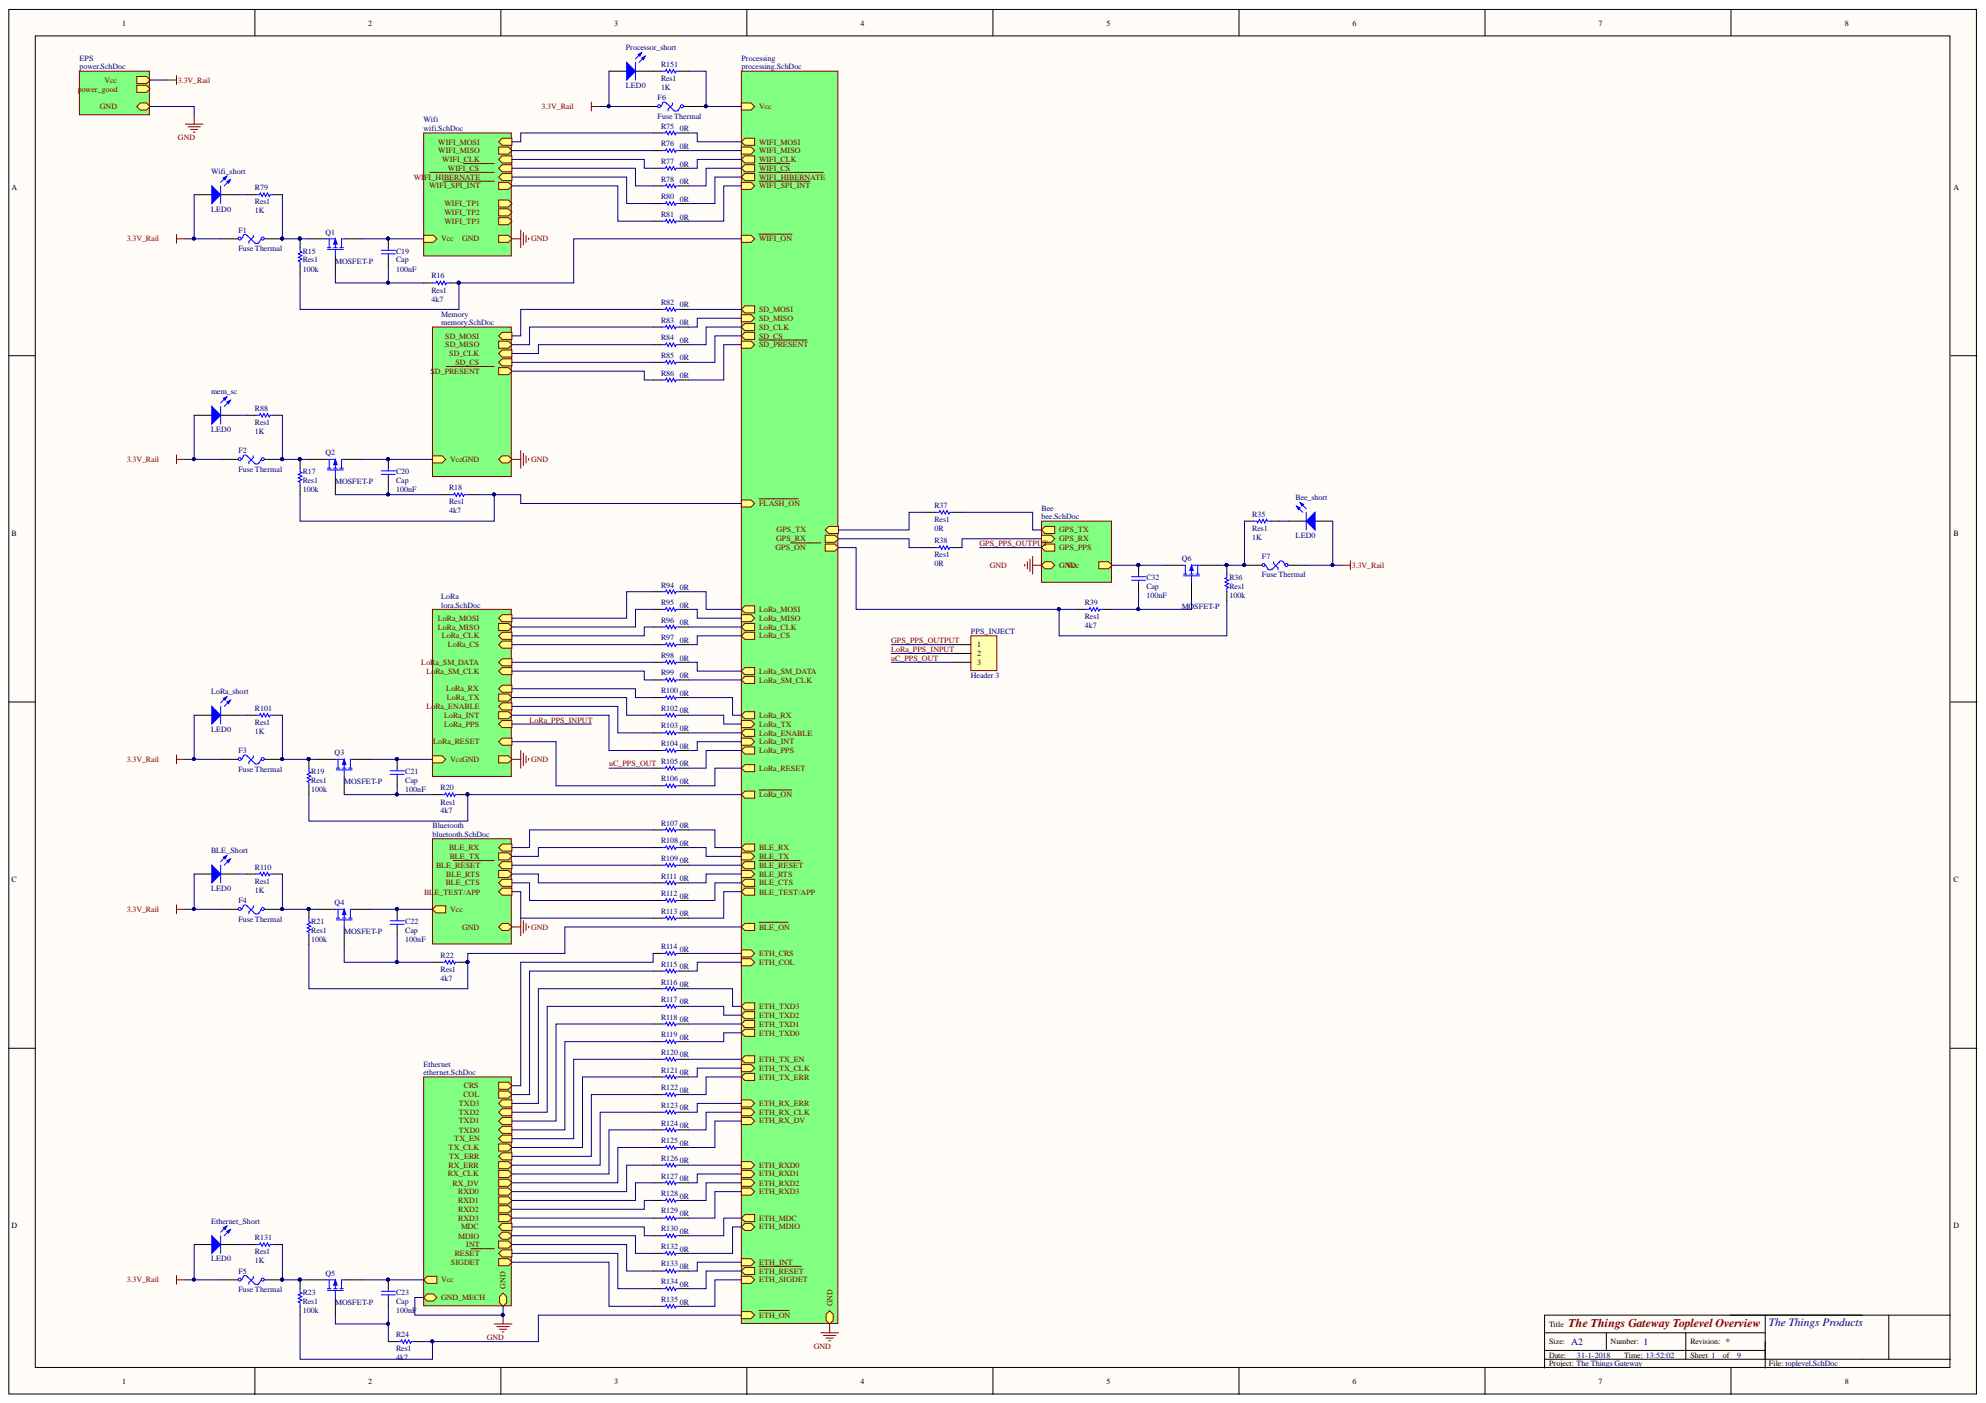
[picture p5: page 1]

The Things Gateway Toplevel Overview
Title

Res1 4k7

Size: A2 | Number: 1 | Revision: *

Project:

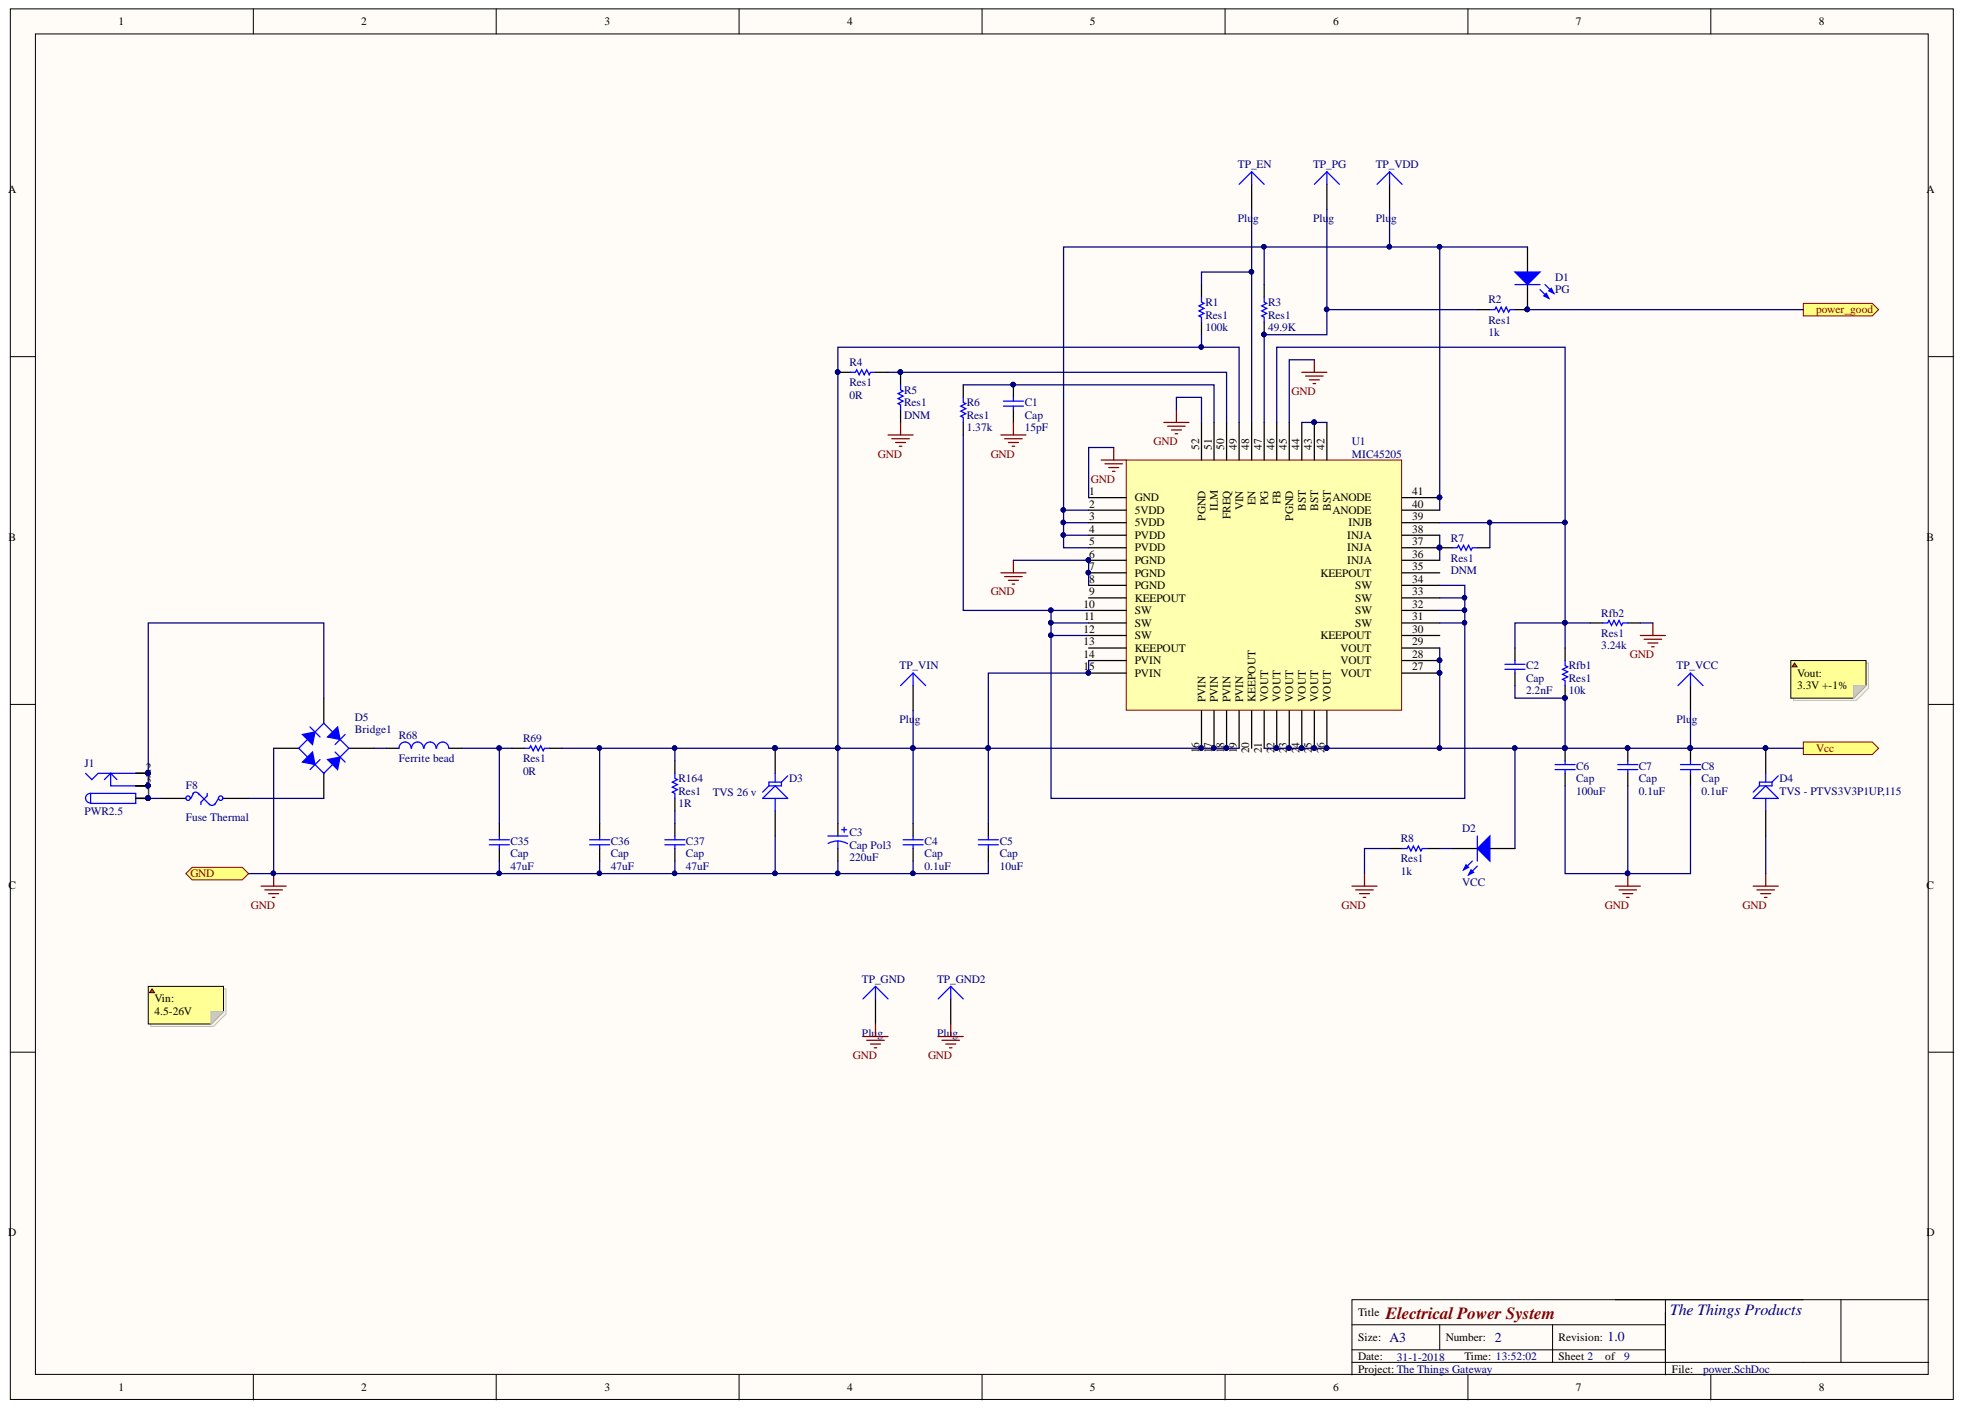
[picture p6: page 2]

BST 42 BST 43 BST 44 PGND 45 FB 46 PG 47 EN 48 VIN 49 FREQ 50 ILM 51 PGND 52

The Things Gateway

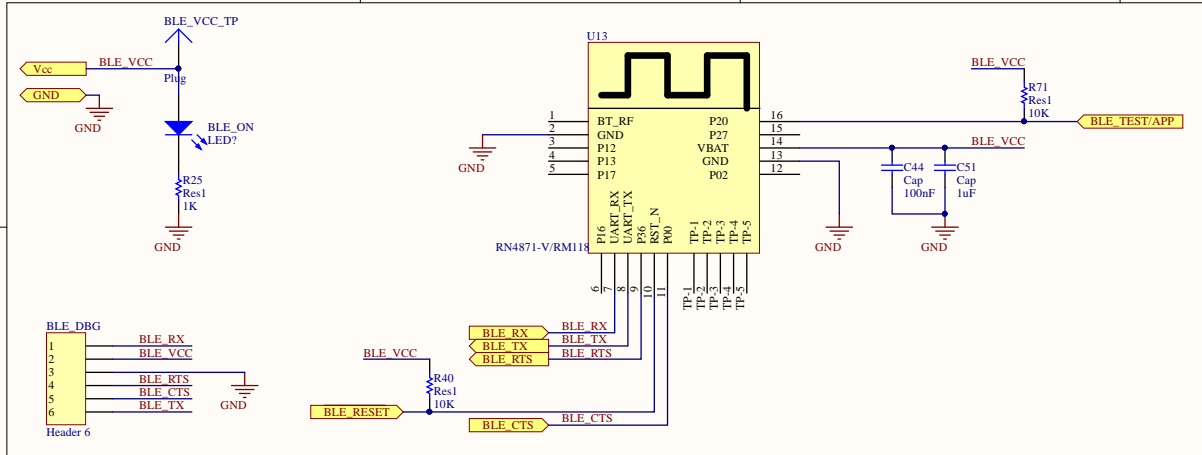
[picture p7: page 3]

Size: A4 | N umber: 3 | Rev i s i o n : 1

Project : T he T h i n g s Gateway

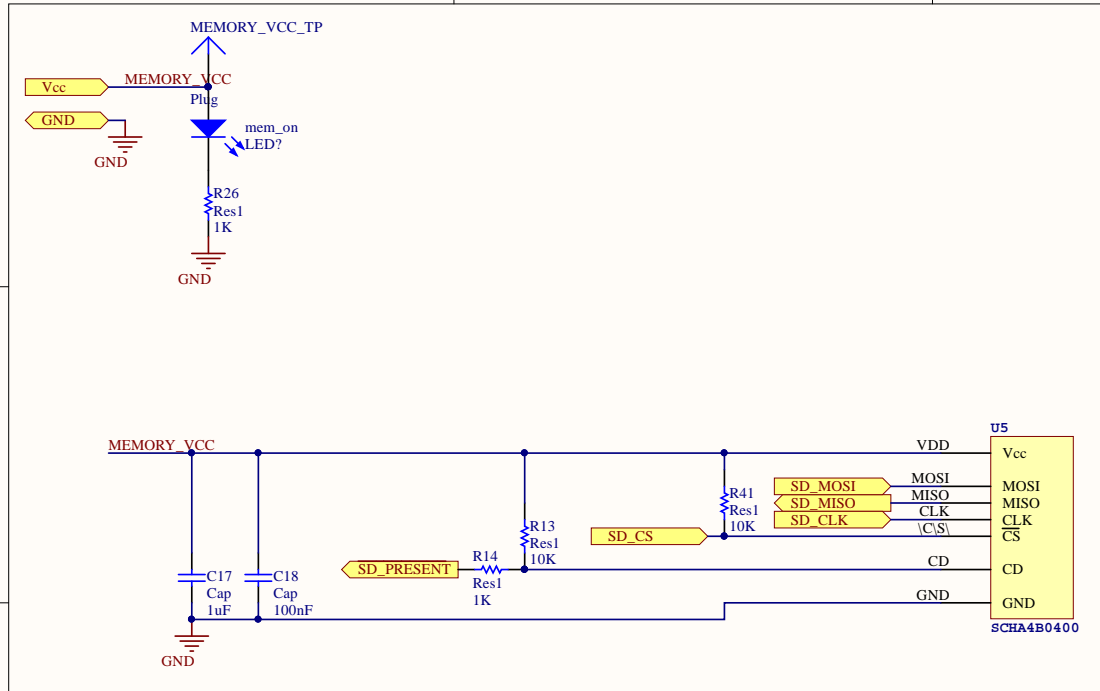
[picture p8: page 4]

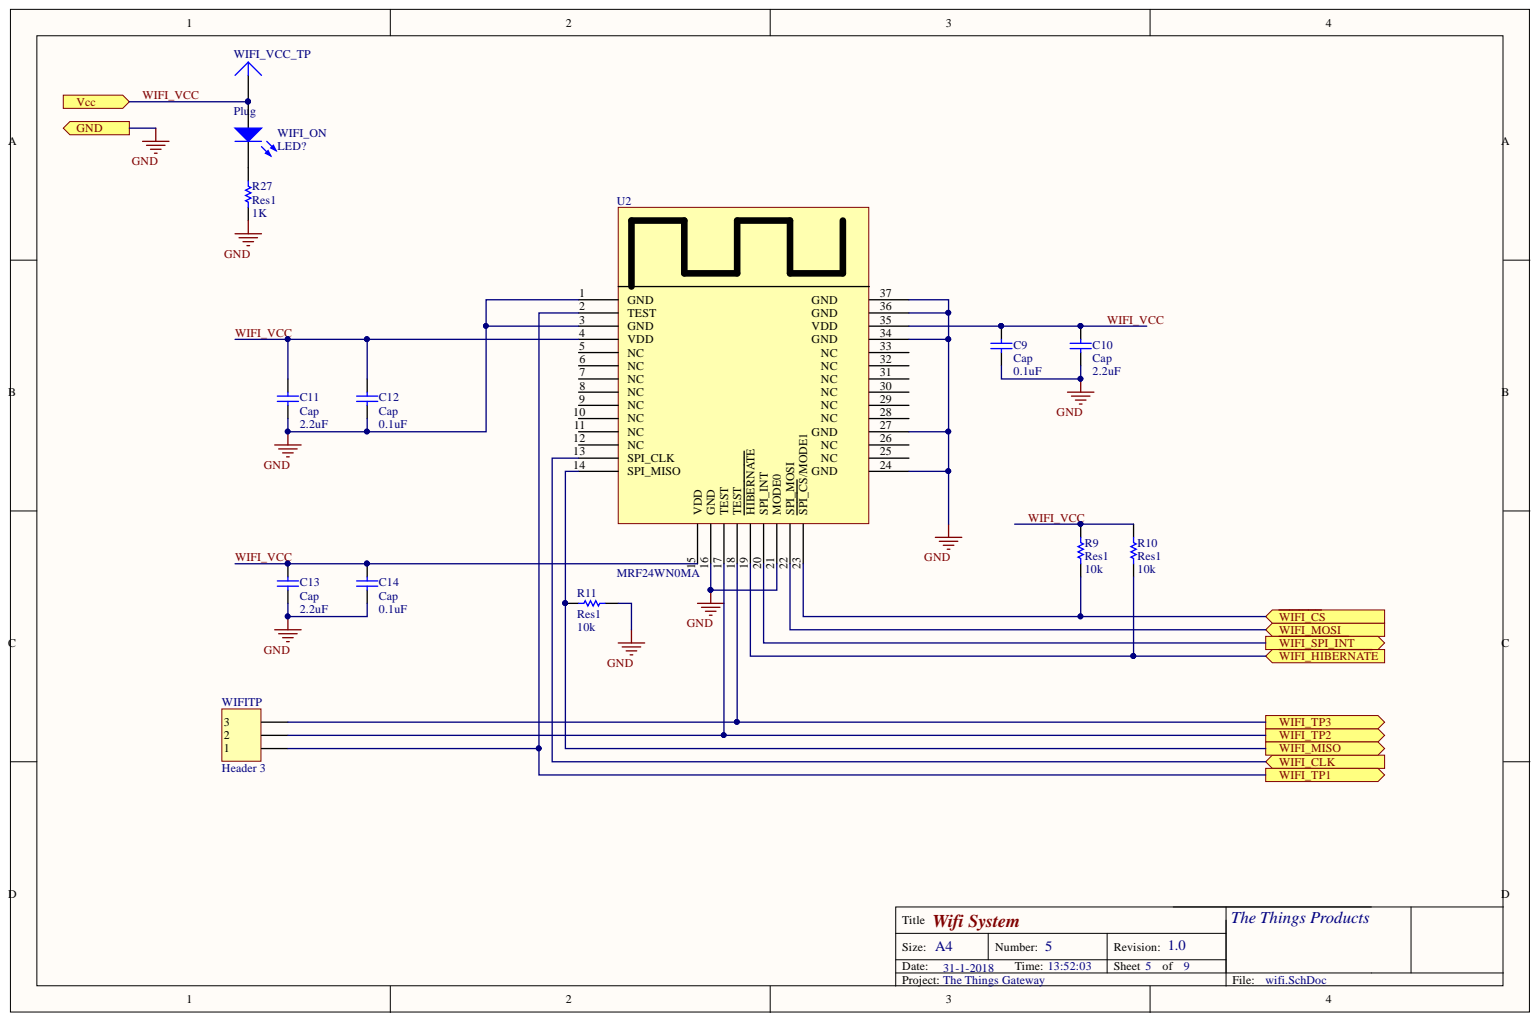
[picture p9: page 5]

2 | | 3 6
1 1 | 3 4 5 | G N D V D D V D D G N D N C N C N C N C N C N C N C N C N C N C N C N C N C G N D N C N C SPI_CL K N C | 3 5 | WIFI_ VCC

Size: A4 | N umber: 5 | Rev i s i o n : 1.0

Project : T he T h i n g s Gateway

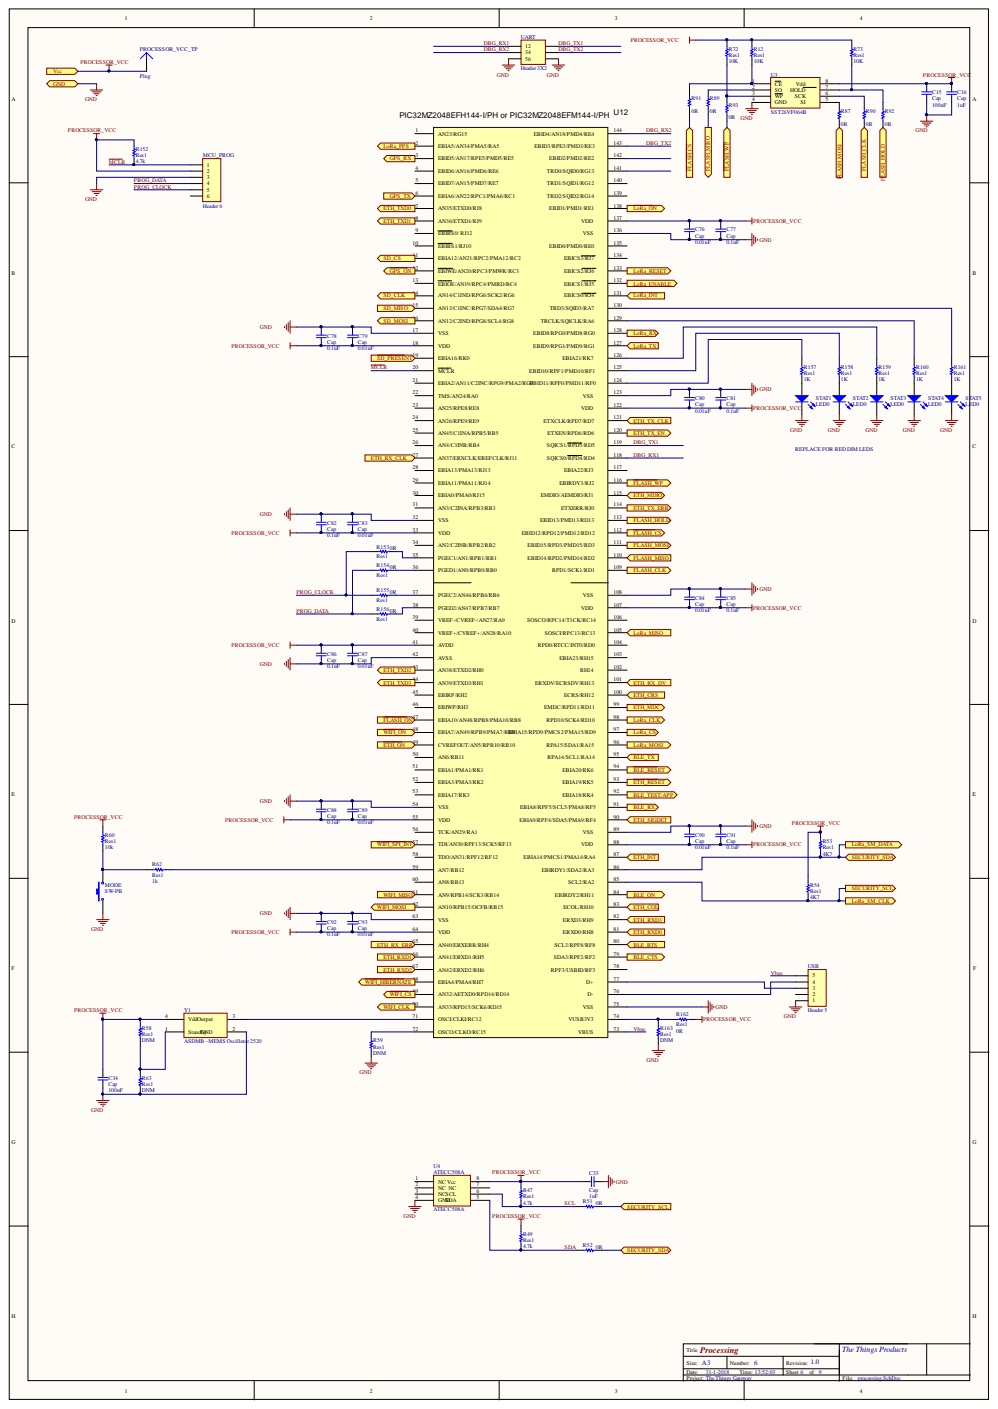
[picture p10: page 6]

REPLACE FOR RED DIM LEDS

4.7k SCL

Processing

File: processing.SchDoc

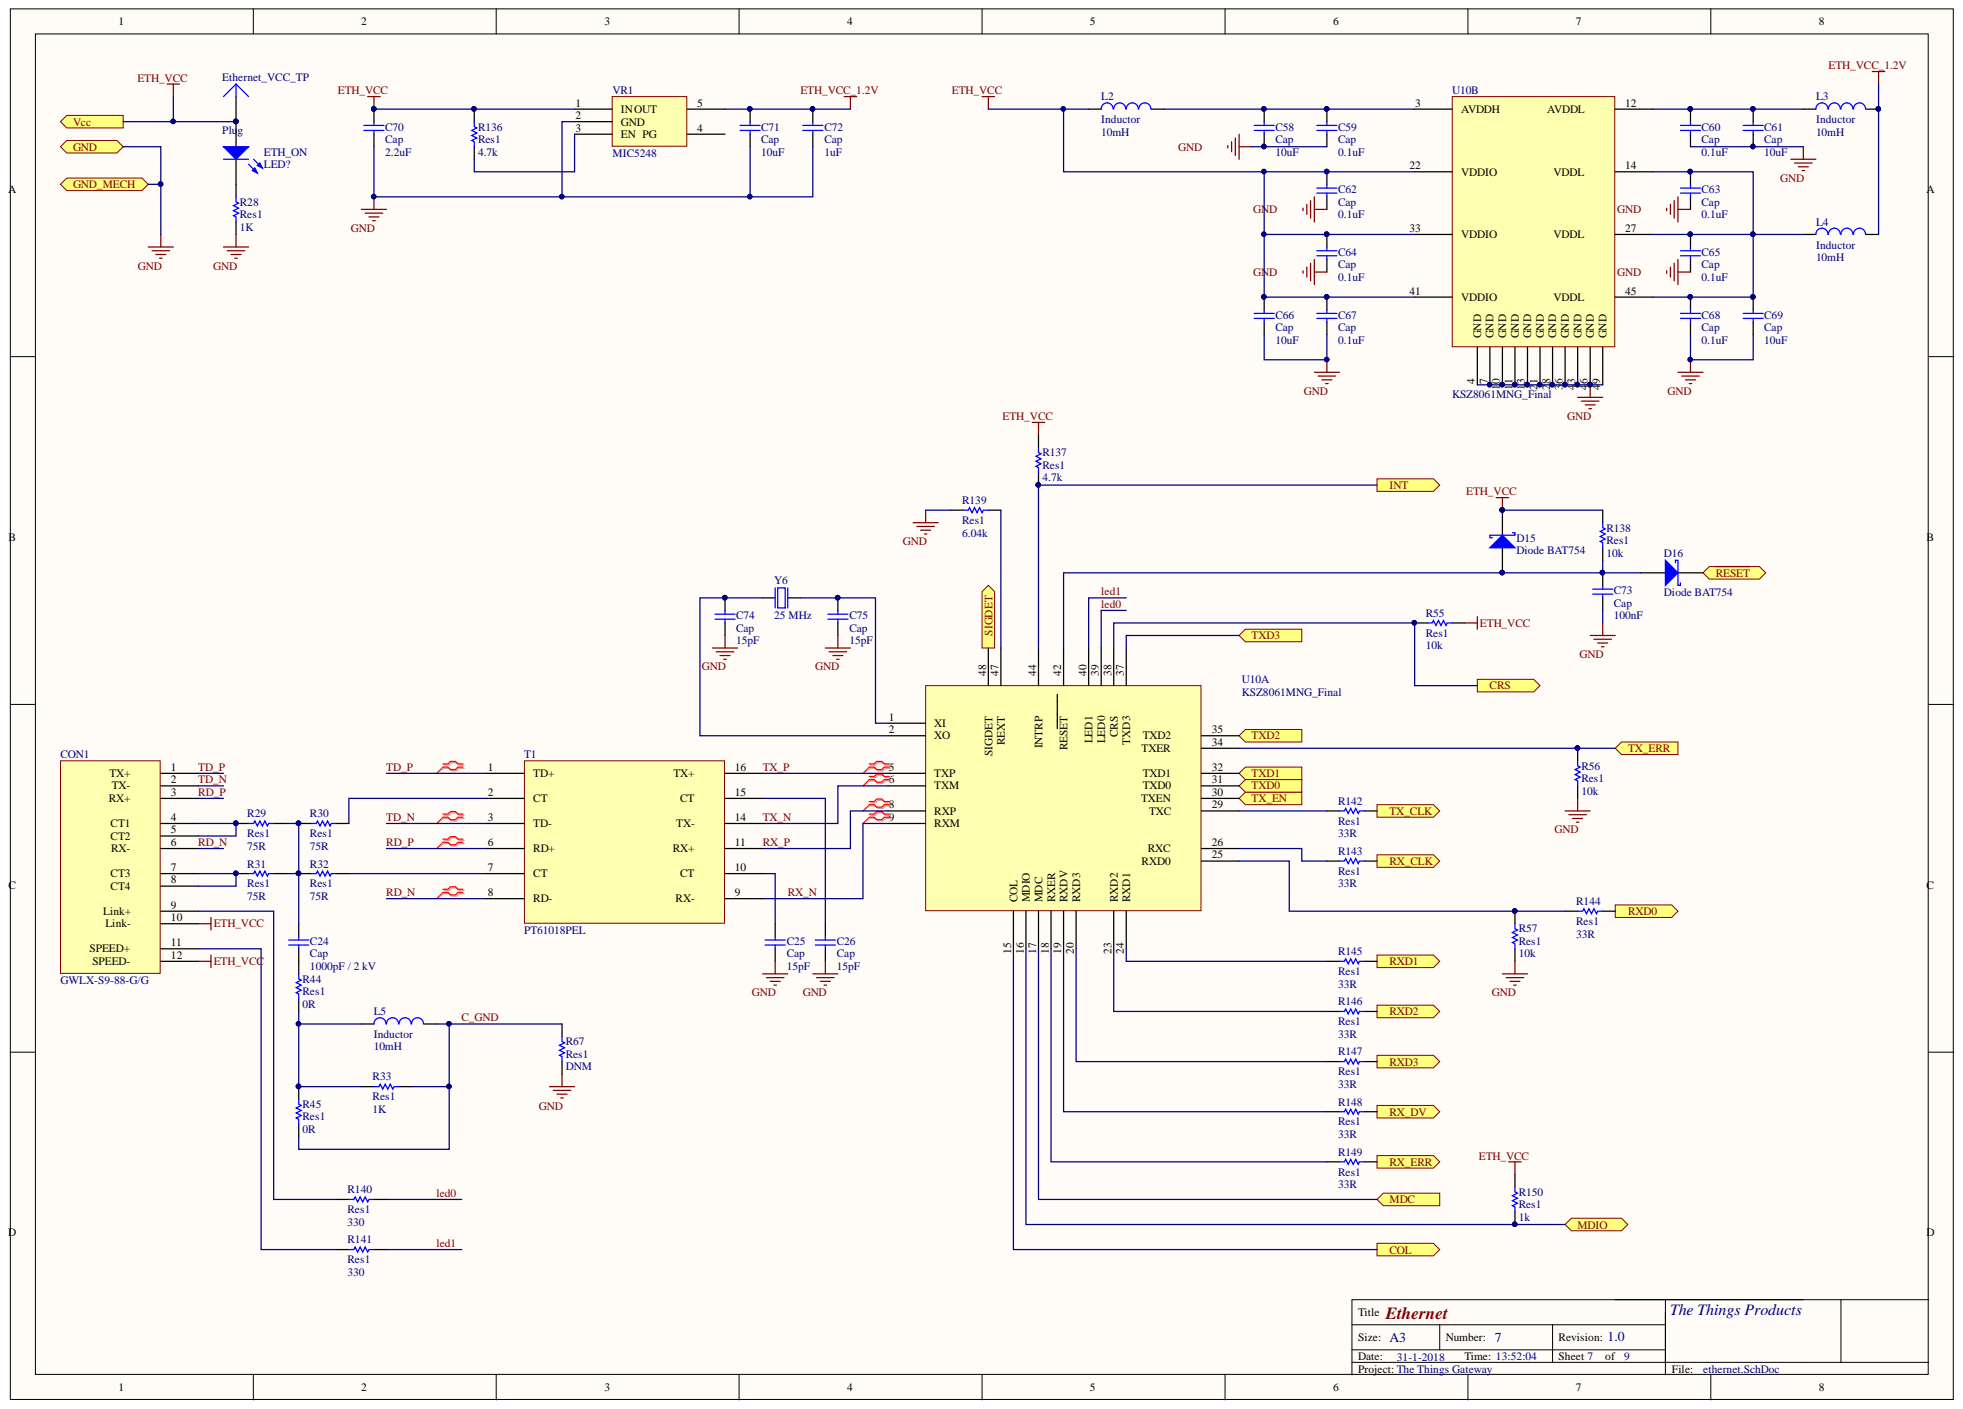
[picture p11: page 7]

Res1

RXP 8

RXD3 20 RXDV 19 RXER 18 MDC 17 MDIO 16 COL 15

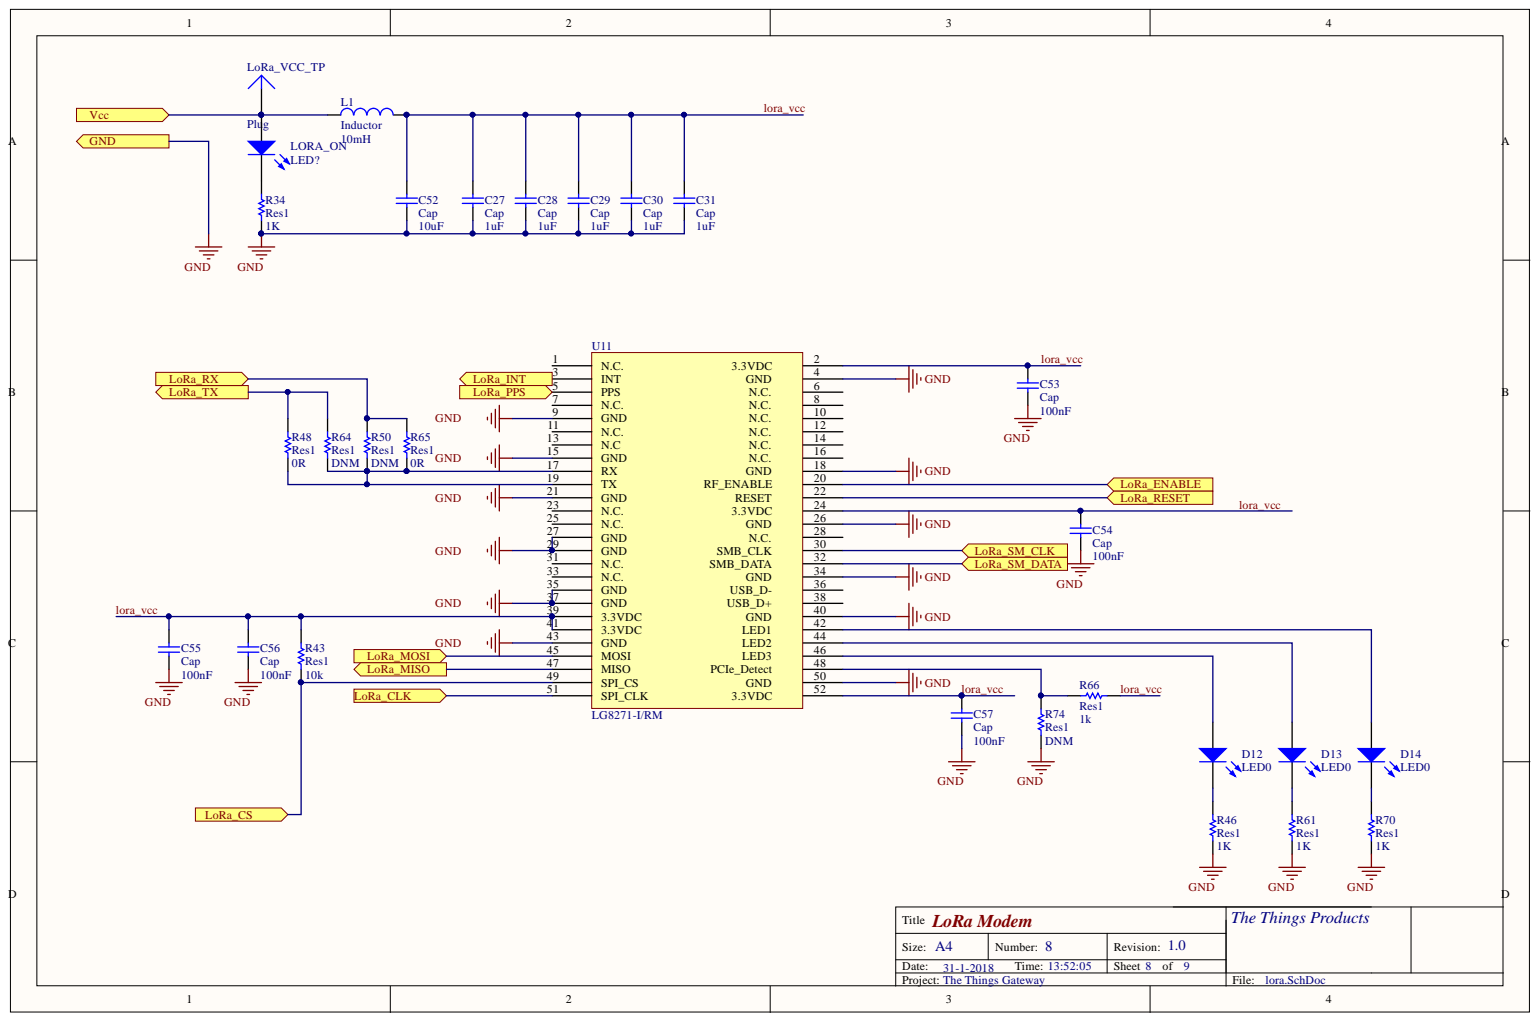
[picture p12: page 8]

lora_vcc

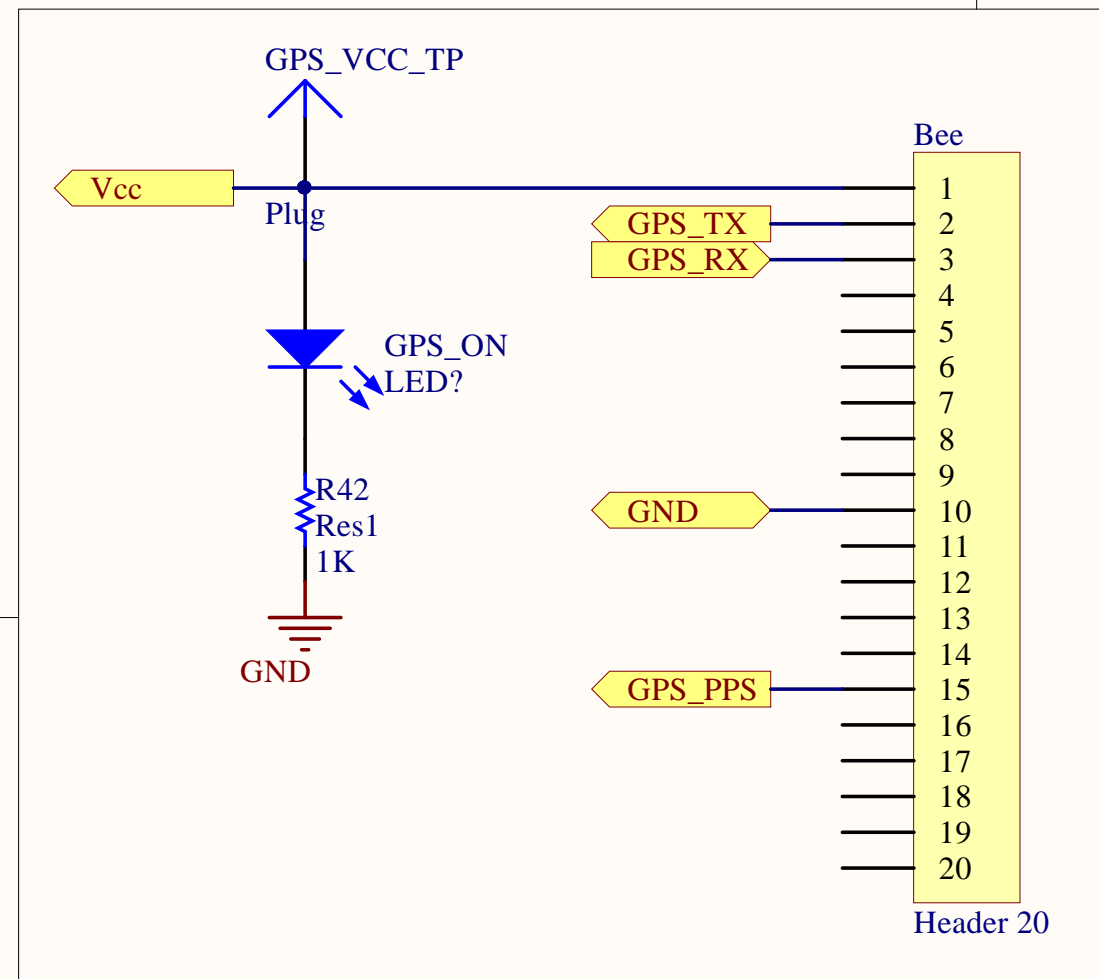
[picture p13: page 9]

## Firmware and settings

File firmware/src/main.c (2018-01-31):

// Copyright © 2016-2018 The Things Products
// Use of this source code is governed by the MIT license that can be found in
// the LICENSE file.

/*******************************************************************************
  MPLAB Harmony Project Main Source File

  Company:
    Microchip Technology Inc.
  


  File Name:
    main.c

  Summary:
    This file contains the "main" function for an MPLAB Harmony project.

  Description:
    This file contains the "main" function for an MPLAB Harmony project.  The
    "main" function calls the "SYS_Initialize" function to initialize the state
    machines of all MPLAB Harmony modules in the system and it calls the
    "SYS_Tasks" function from within a system-wide "super" loop to maintain
    their correct operation. These two functions are implemented in
    configuration-specific files (usually "system_init.c" and "system_tasks.c")
    in a configuration-specific folder under the "src/system_config" folder
    within this project's top-level folder.  An MPLAB Harmony project may have
    more than one configuration, each contained within it's own folder under
    the "system_config" folder.
 *******************************************************************************/

// DOM-IGNORE-BEGIN
/*******************************************************************************
Copyright (c) 2013-2014 released Microchip Technology Inc.  All rights reserved.

//Microchip licenses to you the right to use, modify, copy and distribute
Software only when embedded on a Microchip microcontroller or digital signal
controller that is integrated into your product or third party product
(pursuant to the sublicense terms in the accompanying license agreement).

You should refer to the license agreement accompanying this Software for
additional information regarding your rights and obligations.

SOFTWARE AND DOCUMENTATION ARE PROVIDED "AS IS" WITHOUT WARRANTY OF ANY KIND,
EITHER EXPRESS OR IMPLIED, INCLUDING WITHOUT LIMITATION, ANY WARRANTY OF
MERCHANTABILITY, TITLE, NON-INFRINGEMENT AND FITNESS FOR A PARTICULAR PURPOSE.
IN NO EVENT SHALL MICROCHIP OR ITS LICENSORS BE LIABLE OR OBLIGATED UNDER
CONTRACT, NEGLIGENCE, STRICT LIABILITY, CONTRIBUTION, BREACH OF WARRANTY, OR
OTHER LEGAL EQUITABLE THEORY ANY DIRECT OR INDIRECT DAMAGES OR EXPENSES
INCLUDING BUT NOT LIMITED TO ANY INCIDENTAL, SPECIAL, INDIRECT, PUNITIVE OR
CONSEQUENTIAL DAMAGES, LOST PROFITS OR LOST DATA, COST OF PROCUREMENT OF
SUBSTITUTE GOODS, TECHNOLOGY, SERVICES, OR ANY CLAIMS BY THIRD PARTIES
(INCLUDING BUT NOT LIMITED TO ANY DEFENSE THEREOF), OR OTHER SIMILAR COSTS.
 *******************************************************************************/
// DOM-IGNORE-END

// *****************************************************************************
// *****************************************************************************
// Section: Included Files
// *****************************************************************************
// *****************************************************************************

#include <stddef.h>                   // Defines NULL
#include <stdbool.h>                  // Defines true
#include <stdlib.h>                   // Defines EXIT_FAILURE
#include "system/common/sys_module.h" // SYS function prototypes

#include "subsystem_controller.h"

#include "peripheral/wdt/plib_wdt.h"
#include "peripheral/tmr/plib_tmr.h"
#include "peripheral/reset/plib_reset.h"
#include "peripheral/int/plib_int.h"

#include "trcUser.h"
// *****************************************************************************
// *****************************************************************************
// Section: Main Entry Point
// *****************************************************************************
// *****************************************************************************

int main(void)
{
    // Initialize the WatchDog
    wdt_init();

    // Initialize the FreeRTOS trace recorder
    vTraceInitTraceData();
    uiTraceStart();
    /* Initialize all MPLAB Harmony modules, including application(s). */
    SYS_Initialize(NULL);

    if(wdt_get_reboot_reason() != RESET_REASON_POWERON)
    {
        // Force power off for all modules
        sdSet(false);       // SD card
        wifiSet(false);     // Wifi
        ethernetSet(false); // Ethernet
        loraSet(false);     // LoRa
        bleSet(false);      // BLE

        // Wait before putting modules on (with a busy while-loop as timer is not running yet)
        uint32_t countdown = 100000000;
        for(; countdown > 0; countdown--)
            ;
    }

    statOn();
    sdSet(ON);       // SD card
    wifiSet(ON);     // Wifi
    ethernetSet(ON); // Ethernet
    loraSet(ON);     // LoRa
    bleSet(ON);      // BLE

    while(true)
    {
        /* Maintain state machines of all polled MPLAB Harmony modules. */
        SYS_Tasks();
    }

    /* Execution should not come here during normal operation */

    return (EXIT_FAILURE);
}

/*******************************************************************************
 End of File
*/

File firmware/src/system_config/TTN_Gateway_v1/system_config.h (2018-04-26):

/*******************************************************************************
  MPLAB Harmony System Configuration Header

  File Name:
    system_config.h

  Summary:
    Build-time configuration header for the system defined by this MPLAB Harmony
    project.

  Description:
    An MPLAB Project may have multiple configurations.  This file defines the
    build-time options for a single configuration.

  Remarks:
    This configuration header must not define any prototypes or data
    definitions (or include any files that do).  It only provides macro
    definitions for build-time configuration options that are not instantiated
    until used by another MPLAB Harmony module or application.

    Created with MPLAB Harmony Version 1.08.01
*******************************************************************************/

// DOM-IGNORE-BEGIN
/*******************************************************************************
Copyright (c) 2013-2015 released Microchip Technology Inc.  All rights reserved.

Microchip licenses to you the right to use, modify, copy and distribute
Software only when embedded on a Microchip microcontroller or digital signal
controller that is integrated into your product or third party product
(pursuant to the sublicense terms in the accompanying license agreement).

You should refer to the license agreement accompanying this Software for
additional information regarding your rights and obligations.

SOFTWARE AND DOCUMENTATION ARE PROVIDED AS IS WITHOUT WARRANTY OF ANY KIND,
EITHER EXPRESS OR IMPLIED, INCLUDING WITHOUT LIMITATION, ANY WARRANTY OF
MERCHANTABILITY, TITLE, NON-INFRINGEMENT AND FITNESS FOR A PARTICULAR PURPOSE.
IN NO EVENT SHALL MICROCHIP OR ITS LICENSORS BE LIABLE OR OBLIGATED UNDER
CONTRACT, NEGLIGENCE, STRICT LIABILITY, CONTRIBUTION, BREACH OF WARRANTY, OR
OTHER LEGAL EQUITABLE THEORY ANY DIRECT OR INDIRECT DAMAGES OR EXPENSES
INCLUDING BUT NOT LIMITED TO ANY INCIDENTAL, SPECIAL, INDIRECT, PUNITIVE OR
CONSEQUENTIAL DAMAGES, LOST PROFITS OR LOST DATA, COST OF PROCUREMENT OF
SUBSTITUTE GOODS, TECHNOLOGY, SERVICES, OR ANY CLAIMS BY THIRD PARTIES
(INCLUDING BUT NOT LIMITED TO ANY DEFENSE THEREOF), OR OTHER SIMILAR COSTS.
*******************************************************************************/
// DOM-IGNORE-END

#ifndef _SYSTEM_CONFIG_H
#define _SYSTEM_CONFIG_H

// *****************************************************************************
// *****************************************************************************
// Section: Included Files
// *****************************************************************************
// *****************************************************************************
/*  This section Includes other configuration headers necessary to completely
    define this configuration.
*/

// DOM-IGNORE-BEGIN
#ifdef __cplusplus  // Provide C++ Compatibility

extern "C" {

#endif
// DOM-IGNORE-END

// *****************************************************************************
// *****************************************************************************
// Section: System Service Configuration
// *****************************************************************************
// *****************************************************************************
// *****************************************************************************
/* Common System Service Configuration Options
*/
#define SYS_VERSION_STR           "1.08.01"
#define SYS_VERSION               10801

    
// *****************************************************************************
/* Task size and priorities
 */
#define TASK_SIZE_SYS_TASKS         4096
#define TASK_SIZE_TCPIP_TASKS       4096
#define TASK_SIZE_APP_TASKS         8192
#define TASK_SIZE_LORA_TASKS        4096
//#define TASK_SIZE_LORA_READ         4096  // Defined in app_lora.c, line 1005 (by configMINIMAL_STACK_SIZE)
//#define TASK_SIZE_WIFI_DRV          2048  // Defined in Harmony configuration (CONFIG_DRV_WIFIN_RTOS_MAIN_TASK_SIZE)
//#define TASK_SIZE_MQTT_TASKS        4096  // Hardcoded in MQTTHarmony.c, line 182

#define TASK_PRIORITY_SYS_TASKS     4
#define TASK_PRIORITY_TCPIP_TASKS   6
#define TASK_PRIORITY_APP_TASKS     2
#define TASK_PRIORITY_LORA_TASKS    3
#define TASK_PRIORITY_LORA_READ     7
//#define TASK_PRIORITY_WIFI_DRV      5     // Defined in Harmony configuration (CONFIG_DRV_WIFIN_RTOS_MAIN_TASK_PRIORITY)
//#define TASK_PRIORITY_MQTT_TASKS    1     // Hardcoded in MQTTHarmony.c, line 183
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

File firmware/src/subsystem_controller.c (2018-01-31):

// Copyright © 2016-2018 The Things Products
// Use of this source code is governed by the MIT license that can be found in
// the LICENSE file.

/* ************************************************************************** */
/* ************************************************************************** */
/* Section: Included Files                                                    */
/* ************************************************************************** */
/* ************************************************************************** */

#include "subsystem_controller.h"
#include <stdio.h>
#include <inttypes.h>
#include <stdbool.h>

/* ************************************************************************** */
/* ************************************************************************** */
/* Section: File Scope or Global Data                                         */
/* ************************************************************************** */
/* ************************************************************************** */

static bool wifiOn     = false;
static bool bleOn      = false;
static bool ethernetOn = false;
static bool loraOn     = false;
static bool sdOn       = false;
static bool gpsOn      = false;

static bool stat[5];

/* ************************************************************************** */
/* ************************************************************************** */
// Section: Local Functions                                                   */
/* ************************************************************************** */
/* ************************************************************************** */

/* ************************************************************************** */
/* ************************************************************************** */
// Section: Interface Functions                                               */
/* ************************************************************************** */
/* ************************************************************************** */

void sdSet(bool state)
{
    if(state)
    {
        TRISB = TRISB & (~0x0100); // SD card on
        PORTB = PORTB & (~0x0100);
        sdOn  = true;
    }
    else
    {
        TRISB = TRISB | 0x0100; // SD card off
        PORTB = PORTB | 0x0100;
        sdOn  = false;
    }
}

bool sdIsOn()
{
    return sdOn;
}

void wifiSet(bool state)
{
    if(state)
    {
        TRISB  = TRISB & (~0x0200); // Wifi on
        PORTB  = PORTB & (~0x0200);
        wifiOn = true;
    }
    else
    {
        TRISB  = TRISB | 0x0200; // Wifi off
        PORTB  = PORTB | 0x0200;
        wifiOn = false;
    }
}

bool wifiIsOn()
{
    return wifiOn;
}

void ethernetSet(bool state)
{
    if(state)
    {
        TRISB = TRISB & (~0x0400); // Ethernet on
        PORTB = PORTB & (~0x0400);

        ethernetOn = true;
    }
    else
    {
        TRISB      = TRISB | 0x0400; // Ethernet off
        PORTB      = PORTB | 0x0400;
        ethernetOn = false;
    }
}

bool ethernetIsOn()
{
    return ethernetOn;
}

void loraSet(bool state)
{
    if(state)
    {
        TRISE  = TRISE & (~0x02); // LoRa on
        PORTE  = PORTE & (~0x02);
        loraOn = true;
    }
    else
    {
        TRISE  = TRISE | 0x02; // LoRa off
        PORTE  = PORTE | 0x02;
        loraOn = false;
    }
}

bool loraIsOn()
{
    return loraOn;
}

void bleSet(bool state)
{
    if(state)
    {
        TRISH = TRISH & (~0x0800); // BLE on
        PORTH = PORTH & (~0x0800);
        bleOn = true;
    }
    else
    {
        TRISH = TRISH | 0x0800; // BLE off
        PORTH = PORTH | 0x0800;
        bleOn = false;
    }
}

bool bleIsOn()
{
    return bleOn;
}

void gpsSet(bool state)
{
    if(state)
    {
        TRISC = TRISC & (~0x08); // GPS on
        PORTC = PORTC & (~0x08);
        gpsOn = true;
    }
    else
    {
        TRISC = TRISC | 0x08; // GPS off
        PORTC = PORTC | 0x08;
        gpsOn = false;
    }
}

bool gpsIsOn()
{
    return gpsOn;
}

void statOn()
{
    statSet(0, ON);
    statSet(1, ON);
    statSet(2, ON);
    statSet(3, ON);
    statSet(4, ON);
}

void statOff()
{
    statSet(0, OFF);
    statSet(1, OFF);
    statSet(2, OFF);
    statSet(3, OFF);
    statSet(4, OFF);
}

void statSet(uint8_t stat_num, bool state)
{
    switch(stat_num)
    {
        case 0:
            if(state)
            {
                TRISF = TRISF & (~0x01); // Status LED 1 on
                PORTF = PORTF | 0x01;
            }
            else
            {
                TRISF = TRISF | 0x01; // Status LED 1 off
                PORTF = PORTF & (~0x01);
            }
            break;
        case 1:
            if(state)
            {
                TRISF = TRISF & (~0x02); // Status LED 2 on
                PORTF = PORTF | 0x02;
            }
            else
            {
                TRISF = TRISF | 0x02; // Status LED 2 off
                PORTF = PORTF & (~0x02);
            }
            break;
        case 2:
            if(state)
            {
                TRISK = TRISK & (~0x80); // Status LED 3 on
                PORTK = PORTK | 0x80;
            }
            else
            {
                TRISK = TRISK | 0x80; // Status LED 3 off
                PORTK = PORTK & (~0x80);
            }
            break;
        case 3:
            if(state)
            {
                TRISA = TRISA & (~0x40); // Status LED 4 on
                PORTA = PORTA | 0x40;
            }
            else
            {
                TRISA = TRISA | 0x40; // Status LED 4 off
                PORTA = PORTA & (~0x40);
            }
            break;
        case 4:
            if(state)
            {
                TRISA = TRISA & (~0x80); // Status LED 5 on
                PORTA = PORTA | 0x80;
            }
            else
            {
                TRISA = TRISA | 0x80; // Status LED 5 off
                PORTA = PORTA & (~0x80);
            }
            break;
        default:
            break;
    }
    stat[stat_num] = state;
}

void statToggle(uint8_t stat_num)
{
    if(stat_num > 4)
    {
        return;
    }
    statSet(stat_num, stat[stat_num] ^= ON);
}

bool statIsOn(uint8_t stat_num)
{
    if(stat_num > 4)
    {
        return false;
    }
    return stat[stat_num];
}

/* *****************************************************************************
 End of File
 */

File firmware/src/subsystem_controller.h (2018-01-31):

// Copyright © 2016-2018 The Things Products
// Use of this source code is governed by the MIT license that can be found in
// the LICENSE file.

#ifndef _SUBSYSTEM_CONTROLLER_H /* Guard against multiple inclusion */
#define _SUBSYSTEM_CONTROLLER_H

/* ************************************************************************** */
/* ************************************************************************** */
/* Section: Included Files                                                    */
/* ************************************************************************** */
/* ************************************************************************** */

#include "app.h"
#include <stdbool.h>
#include <inttypes.h>

/* Provide C++ Compatibility */
#ifdef __cplusplus
extern "C"
{
#endif

    /* ************************************************************************** */
    /* ************************************************************************** */
    /* Section: Constants                                                         */
    /* ************************************************************************** */
    /* ************************************************************************** */

#define OFF 0
#define ON 1

#define LED1 0
#define LED2 1
#define LED3 2
#define LED4 3
#define LED5 4

#define LED_POWER LED1
#define LED_INTERNET LED2
#define LED_ACTIVATION LED3
#define LED_MQTT LED4
#define LED_ACTIVITY LED5

    // *****************************************************************************
    // *****************************************************************************
    // Section: Interface Functions
    // *****************************************************************************
    // *****************************************************************************

    void sdSet(bool state);
    bool sdIsOn();

    void wifiSet(bool state);
    bool wifiIsOn();

    void ethernetSet(bool state);
    bool ethernetIsOn();

    void loraSet(bool state);
    bool loraIsOn();

    void bleSet(bool state);
    bool bleIsOn();

    void gpsSet(bool state);
    bool gpsIsOn();

    void statOn();
    void statOff();

    void statSet(uint8_t stat_num, bool state);
    void statToggle(uint8_t stat_num);
    bool statIsOn(uint8_t stat_num);

/* Provide C++ Compatibility */
#ifdef __cplusplus
}
#endif

#endif /* _SUBSYSTEM_CONTROLLER_H */

/* *****************************************************************************
 End of File
 */

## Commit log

2018-01-31 Add Gateway Enclosure Designs
    [TheThingsGateway-lightguide.STEP, TheThingsGateway-middle.STEP, TheThingsGateway-top.STEP]
2018-01-31 Add Gateway Hardware Designs
    [TTN_Gateway_V2.3.1.PcbLib, TTN_Gateway_V2.3.1.PrjPcb, TTN_Gateway_V2.3.1.SCHLIB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]
2018-02-11 Issue #1: flushing UART, extended logging
    [app_lora.c]
2018-02-11 Issue #1: removed excessive flushing; documentation; removed trailing whitespace
    [app_lora.c]
2018-02-16 Add LEDs doc
2018-03-12 Fixed crash on downlink due to illegal flush in async mode
    [app_lora.c]
2018-03-22 Report LoRa UART errors and disable error interrupt
2018-03-22 Switching UART to lower bautrate when running on FRC
2018-04-04 Removed switch to AP on timeout and on max ping retries. Return to STATE_WAIT_FOR_NETWORK instead.
2018-04-21 Increase ping timeout interval
    The previous WiFi patch that restricted AP mode to only when there is no WiFi config causes issues with gateways with exisiting WiFi config.
    Though the two are not directly related, the patch seems to have uncovered an existing problem.
    In the current code, the WiFi ping timeout is 8s (4x2 tries). But practically, it takes 10-15s to re-connect. So, after 8s, we go to WAIT_FOR_NETWORK state where the WiFi module is restarted.
    This causes a loop since everytime the pings timeout at 8s and restart the WiFi module.
    By increasing the ping timeout to a higher value of 120s (60x2 tries), this issue is not observed since the WiFi connects after roughly after 15-20s.
    T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
2018-04-26 Fixed app stack size
    Print stack high water marks of sys, app, tcpip, lora tasks.
    Increased app stack from 4k to 8k.
    [system_config.h]
2018-04-26 Revert LoRa changes in 1.0.3.
    [app.h, app_lora.c, system_init.c]
2019-05-17 Bump version
    With this patch we add the ISRG Root X1 CA to the gateway firmware. After 8 July 2019, many servers that use Let's Encrypt will start serving a certificate chain which leads to this new root, and the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
2022-09-11 On MQTT socket timeout go to error state
2022-09-11 Patch ttn-gateway-connector parameters
2023-05-05 Fix LoRa standard channel setup
    [app_lora.c]
2023-05-05 Fix FSK channel setup
    [app_lora.c]
